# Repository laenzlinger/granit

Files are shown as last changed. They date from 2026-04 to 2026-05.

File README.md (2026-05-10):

# Granit — Offsite Backup Device

Custom carrier board for the Raspberry Pi CM4 Compute Module, designed as a minimal offsite backup appliance.

📖 **[Documentation](https://laenzlinger.github.io/granit/latest/)**




## Overview

PCB 3D Render

A compact, headless device that connects to a remote network and receives encrypted backups
onto an attached hard disk. Designed to be left at a trusted offsite location and managed remotely.

- Raspberry Pi CM4 with PCIe SATA (ASM1061)
- 2.5" or 3.5" HDD/SSD support
- Software-controlled HDD power (GPIO)
- RTC wake for scheduled backups
- USB-C OTG for eMMC flashing
- Hammond 1455 aluminium enclosure

## Roadmap

- **v0.3** — First production run (CM4, 4-layer PCB, JLCPCB)
- **v0.4** — Fix wake/shutdown latch (#31), barrel jack swap (#40), DF40C alignment bosses (#37)
- **v1.0** — Validated design with custom OS image and documentation
- **Future** — Investigating RISC-V SoM support for a fully blob-free variant

## License

[CERN Open Hardware Licence Version 2 - Permissive](https://ohwr.org/cern_ohl_p_v2.txt)

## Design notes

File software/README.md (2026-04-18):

# Granit OS Image & Configuration

## Architecture

- **pi-gen**: builds a minimal Raspberry Pi OS Lite image (packages + boot config)
- **Ansible**: configures all services, security, and monitoring

This split means you can either:
1. Flash the custom image and it's ready to provision
2. Flash stock Raspberry Pi OS and run `make provision`

## Quick Start

```bash
# Option A: Build custom image
make build
# Flash to eMMC via rpiboot + rpi-imager

# Option B: Use stock Raspberry Pi OS Lite
# Flash via rpi-imager, boot, connect Ethernet

# Then provision via Ansible
make provision
```

## Configuration

After provisioning, edit `/etc/granit/sync.conf`:

```bash
SYNC_REMOTE=":sftp,host=100.x.x.x,user=backup,key_file=/home/granit/.ssh/id_ed25519:/backups"
WAKE_HOUR=04
METRICS_URL="http://192.168.1.x:8428/api/v1/import/prometheus"
```

Then enable the backup cycle:

```bash
sudo systemctl enable --now granit-cycle.timer
```

## Ansible Variables

| Variable | Default | Description |
|---|---|---|
| `granit_timezone` | `UTC` | System timezone |
| `granit_wake_hour` | `04` | RTC wake hour (24h) |
| `granit_sync_remote` | `""` | rclone remote path |
| `granit_metrics_url` | `""` | Prometheus remote-write URL |

## Structure

```
software/
├── Makefile              # build image or provision
├── hardware-test.sh      # hardware validation script
├── pi-gen/               # image build (packages + boot config)
│   ├── config
│   └── stage-granit/
│       ├── 00-install-packages/
│       └── 01-config/
└── ansible/              # device configuration
    ├── playbook.yml
    ├── inventory/
    └── roles/granit/
        ├── tasks/main.yml
        ├── templates/
        └── files/
```

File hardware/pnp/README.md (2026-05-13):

# Pick and Place Assembly Plan

OpenPnP job files for Granit v0.3 prototype assembly.

## Usage

```bash
cd hardware
make pnp        # generate board.xml + ensure parts exist
make feeders    # assign parts to feeder slots
make feeder-map # generate interactive HTML feeder map
```

## Feeder Allocation

Defined in [`feeders.csv`](feeders.csv) — the single source of truth for
which part goes in which feeder slot. Apply with `make feeders`.

View the interactive feeder map with `make feeder-map`.

## Hand-Place Components

| Ref | Part | Reason |
| --- | ---- | --- |
| CM1 | Raspberry Pi CM4 | Board-to-board connector |
| J1 | USB-C receptacle | Mid-mount, alignment |
| J3 | UART connector | Vertical |
| J4 | SATA 22-pin | Through-hole pins |

## Assembly Sequence

1. **Stencil** — apply solder paste (tape-hinge, align under microscope)
2. **Machine place** — run OpenPnP job (90 placements)
3. **Inspect** — check QFN-48 (U3) alignment
4. **Reflow** — reflow oven (peak ~210°C leaded / ~245°C lead-free)
5. **Inspect** — check for bridges
6. **Hand-solder** — CM1, J1, J3, J4
7. **Clean** — IPA wash

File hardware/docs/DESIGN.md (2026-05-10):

# Hardware Design Notes

Detailed design decisions and PCB routing guidelines for the Granit carrier board.

## SATA Power Switching

12V and 5V to the SATA connector are switched by P-channel MOSFETs
(Q2, Q3 — FDS4435BZ). GPIO17 (`SATA_PWR_EN`) drives N-channel level shifters
(Q5, Q6 — 2N7002) which pull the P-FET gates low to turn them on.

```
Supply (+12V or +5VP)
  │
  JP5/JP6 pad 1 ─── [bridged default] ─── JP5/JP6 pad 2 (common)
                                              │
  JP5/JP6 pad 3 ─── GND                  R12/R13 (100K)
                                              │
                                         ┌────┴──── Q2/Q3 gate
                                         │
                                    2N7002 drain
                                         │
  SATA_PWR_EN (GPIO17) ── R14 (10K) ── 2N7002 gate
                                         │
                                    2N7002 source
                                         │
                                        GND
```

Two 3-pad solder jumpers (JP5 `SATA_12V_PWR`, JP6 `SATA_5V_PWR`) select the boot default:
- **Pads 1-2 bridged (default):** 100K pull-up to source → FETs OFF → HDD powered on by software
- **Pads 2-3 bridged:** 100K pull-down to GND → FETs ON → HDD powered at boot

GPIO17 high → N-FET on → P-FET gate low → SATA power on.
GPIO17 low or high-Z (boot default) → N-FET off → pull-up holds P-FET off.

R14 (10K) protects GPIO17 against N-FET gate-to-drain failure.

## Power Routing & Netclasses

PCB is fabricated with JLCPCB standard 4-layer stackup (1oz / 35µm copper on all layers).
Track widths are sized per IPC-2221 for outer-layer traces with 20°C temperature rise.

| Netclass | Track Width | Via (pad/drill) | Capacity (1oz, 20°C rise) | Worst-case Load | Nets |
|---|---|---|---|---|---|
| Power 12V | 3.0mm | 1.6mm / 0.8mm | ~3.5A | ~2.5A | `+12V*`, `fused`, `unfused` |
| Power 5V | 2.5mm | 1.6mm / 0.8mm | ~3.2A | ~2.8A | `+5VP`, `VBUS`, `switch` |
| Power 3V3 | 1.0mm | 0.8mm / 0.4mm | ~1.5A | ~0.6A | `+3V3` |

### Routing Guidelines

- Netclass widths are the default for main runs. Neck down to pad width over the last 1–2mm at component pads.
- Use copper pours for 12V and 5V in the PSU area where space allows.
- Use 2–3 parallel vias where power traces change layers.
- Place GND return vias near every power via.
- Keep 12V and 5V routing on top/bottom layers — do not break the inner GND planes.
- Do not route power traces under or parallel to PCIe/SATA/Ethernet differential pairs.

### Layer Strategy

- **Top layer:** PSU components and local routing, signal components
- **Inner 1 (In1.Cu):** GND plane — keep unbroken
- **Inner 2 (In2.Cu):** GND plane — keep unbroken
- **Bottom layer:** Power distribution (5V, 12V, 3.3V to rest of board), signal routing

### Signal Integrity

- **PCIe:** 100Ω differential impedance, matched length, minimize vias and stubs
- **SATA:** 100Ω differential impedance, matched length
- **Ethernet:** 100Ω differential impedance to RJ45 with magnetics
- **USB:** 90Ω differential impedance
- Power traces crossing differential pairs must cross perpendicular (90°)

### AC Coupling Capacitors

6× 100nF 0805 in series on high-speed differential pairs, all placed near the ASM1061:

- **SATA TX** (STXP_A, STXN_A): required by SATA spec (ASM1061 datasheet CTX = 75–200nF)
- **SATA RX** (SRXP_A, SRXN_A): defensive — external interface, can't guarantee drive-side caps
- **PCIe RX** (PCIE_RX_P, PCIE_RX_N): required by CM4 datasheet ("external AC coupling capacitor required")
- **PCIe TX, CLK**: not needed — CM4 has internal AC coupling
- **Ethernet**: not needed — MagJack provides galvanic isolation
- **USB**: not needed — DC-coupled by spec

### ESD Protection

- **USB-C** (J7): USBLC6-2SC6 on D+/D− — user-facing external connector, required
- **SATA** (J9): no ESD protection — internal connector inside metal enclosure, not user-accessible, AC coupling caps provide DC fault isolation
- **Ethernet** (J3): RJ45 MagJack has integrated common-mode chokes and 2kV isolation

## Power Budget

| Rail | Source | Capacity | Worst-case Load |
|---|---|---|---|
| 12V | External PSU | 3A+ recommended | ~2.5A (HDD spin-up + buck converter) |
| 5V | AP64501SP-13 | 3.5A | ~2.8A (CM4 + HDD + USB) |
| 3.3V | NCP1117 LDO | 1A | ~0.6A (ASM1061 + RTC + misc) |

Realistic steady state: ~1.5A (CM4) + 0.5A (HDD) = 2.0A on 5V rail.
HDD spin-up and CM4 peak don't occur simultaneously — SATA power is software-controlled.

### 5V Rail Voltage (5.16V)

The feedback divider (R2=12K, R4=2.2K) sets the buck converter output to 5.16V, intentionally above 5.0V:

- **SATA power FET drop**: FDS4435BZ Rds(on) ~9mΩ → ~18mV loss at 2A
- **Trace/connector resistance**: additional ~30–50mV drop to CM4 pins
- **CM4 undervoltage threshold**: the CM4 triggers low-voltage warnings below ~4.9V

Running at 5.16V ensures the CM4 sees >5.0V after all drops, avoiding undervoltage throttling.

## Ethernet MagJack Pin Mapping

The HR911130A (Hanrun) GbE MagJack follows the standard TIA-568B MDI (Medium Dependent
Interface) pinout. The RJ45 jack pins 1–8 map to Ethernet pairs through internal isolation
transformers, with the transformer outputs on PCB-side pins P1–P10.

### TIA-568B MDI Pair Assignment

In Gigabit Ethernet (1000BASE-T), all 4 pairs are bidirectional. The pair numbering follows
TIA-568B:

| RJ45 Jack Pins | MDI Pair | Function (legacy 10/100) |
|---|---|---|
| 1, 2 | Pair 0 | TX |
| 3, 6 | Pair 1 | RX |
| 4, 5 | Pair 2 | BI (GbE only) |
| 7, 8 | Pair 3 | BI (GbE only) |

Note: Pair 1 (pins 3 and 6) is intentionally split across pins 4 and 5 on the RJ45 jack.
This is a TIA-568 design choice for backwards compatibility with 2-pair telephone wiring.

### HR911130A PCB-Side Pin Mapping

| PCB Pin | Signal | CM4 Net | Notes |
|---|---|---|---|
| P1 | Center tap (primary) | +3.3V via bias resistor | Transformer center tap bias |
| P2 | MDI Pair 0+ | ETH_P0_P | |
| P3 | MDI Pair 0− | ETH_P0_N | |
| P4 | MDI Pair 1+ | ETH_P1_P | Physically far from P7 — normal per TIA-568 |
| P5 | MDI Pair 2+ | ETH_P2_P | |
| P6 | MDI Pair 2− | ETH_P2_N | |
| P7 | MDI Pair 1− | ETH_P1_N | Physically far from P4 — normal per TIA-568 |
| P8 | MDI Pair 3+ | ETH_P3_P | |
| P9 | MDI Pair 3− | ETH_P3_N | |
| P10 | Center tap (secondary) | GND via RC network | Bob Smith termination |
| 11 | LED Green anode | +3.3V via resistor | Link/Activity |
| 12 | LED Green cathode | nLED1 | |
| 13 | LED Yellow cathode | nLED2 | |
| 14 | LED Yellow anode | +3.3V via resistor | Speed |
| S1, S2 | Shield | GND | Chassis ground |

### Routing Notes

- P4 and P7 (Pair 1) are physically separated on the PCB pads because the MagJack's
  internal transformers mirror the RJ45 jack pin arrangement where pins 3 and 6 are split.
  Route them as a matched-length differential pair despite the physical separation at the
  MagJack end.
- All 4 Ethernet pairs require 100Ω differential impedance and length matching.
- The MagJack provides galvanic isolation (2kV) — no external AC coupling or ESD protection
  needed on the Ethernet lines.

## GLOBAL_EN Wake/Shutdown Latch

Controls CM4 power state via the GLOBAL_EN pin (pin 99). Supports cold boot, software
shutdown with latch, RTC alarm wake, and button wake.

### Background

GLOBAL_EN has a CM4-internal pull-up — the module boots when GLOBAL_EN is HIGH or floating,
and powers off completely when GLOBAL_EN is held LOW. After shutdown, CM4 GPIOs go Hi-Z,
so a hardware latch is required to hold GLOBAL_EN LOW and prevent immediate reboot.

### Failed Approach (v0.3)

The v0.3 design used an OR gate (U4, 74AHCT1G32) driving GLOBAL_EN HIGH on wake events,
with Q1 (2N7002) gated by RTC ~INT. R19 (10K pull-up on Q1 gate) held Q1 ON at power-on,
pulling U4 input LOW and preventing boot. The logic was fundamentally inverted.

Workaround: R19 removed. RTC wake non-functional.

### Redesigned Circuit (proposed for v0.4)

Uses a 74LVC1G74 D flip-flop as an SR latch via asynchronous ~PRE (set) and ~CLR (reset).

```
                          ┌───────────────────┐
        RTC ~INT ─────────┤ ~PRE           Q  ├──────── GLOBAL_EN (CM4 pin 99)
                          │                   │
        BUTTON ───────────┤        74LVC1G74  │
                          │                   │
        GPIO6 ────────────┤ ~CLR              │
                          │                   │
                     GND ─┤ CLK            D  ├── GND
                          │                   │
                    +3V3 ─┤ VCC          GND  ├── GND
                          └───────────────────┘

        ~PRE pin external components:
            R1 (100K) ── ~PRE to GND        power-on: forces Q=HIGH via RC delay
            C1 (100nF) ─ ~PRE to GND        holds ~PRE LOW during 3V3 ramp (~10ms)

        ~CLR pin external components:
            R2 (100K) ── ~CLR to +3V3       prevents accidental shutdown at boot

        Existing pull-ups (kept):
            R19 (10K) ── RTC ~INT to +3V3   releases ~PRE HIGH when no alarm
            R6  (10K) ── BUTTON to +3V3     releases ~PRE HIGH when not pressed
```

CLK and D are tied to GND — no clocked operation, only async ~PRE/~CLR control Q.

### Operation

| State | ~PRE | ~CLR | Q (GLOBAL_EN) | Result |
|---|---|---|---|---|
| Cold power-on | LOW (C1 holds during ramp) | HIGH (R2) | HIGH | Boots |
| Running | HIGH (R19+R6 overpower R1) | HIGH | HIGH (latched) | Stays on |
| Shutdown | HIGH | LOW (GPIO6) | LOW | Off |
| Sleeping | HIGH | HIGH (GPIO6 Hi-Z, R2) | LOW (latched) | Stays off |
| RTC wake | LOW (~INT asserts) | HIGH | HIGH | Boots |
| Button wake | LOW (pressed) | HIGH | HIGH | Boots |

### Conflict: ~PRE=LOW and ~CLR=LOW Simultaneously

Per TI SN74LVC1G74 datasheet: both asserted → Q=HIGH (nonstable state). Wake wins over
shutdown. When one releases, output follows whichever remains asserted. This is safe — the
device cannot be held off while a wake event is active.

### Power-On Timing

R1 (100K) + C1 (100nF) gives τ = 10ms. During 3V3 ramp-up, C1 holds ~PRE below VIL,
forcing Q=HIGH. Once 3V3 stabilizes, R19 (10K) and R6 (10K) overpower R1 (100K) and
bring ~PRE HIGH. The latch then holds Q=HIGH until ~CLR is asserted.

### RTC ~INT Lock-Out

DS3231 ~INT is level-triggered — stays LOW until the alarm flag is cleared via I2C. While
~INT is LOW, ~PRE is asserted and the latch cannot be reset (shutdown is blocked). This is
acceptable because GLOBAL_EN must be HIGH during boot anyway. The boot script must clear
the alarm early:

```bash
i2cset -y 1 0x68 0x0F 0x00  # Clear DS3231 status register (alarm flags)
```

### GPIO6 Float Protection

GPIO6 defaults to Hi-Z (input) at boot. R2 (100K to +3V3) keeps ~CLR HIGH, preventing
accidental shutdown. GPIO6 has no boot-time alternate function that would drive it LOW.

### Debouncing

Not required. ~PRE is level-sensitive — button bounce repeatedly forces Q=HIGH, which is
idempotent. CM4 PMIC power-up (~100ms) is far slower than bounce (~1–10ms).

### Parts Change from v0.3

| Remove | Add |
|---|-----|
| U4 (74AHCT1G32) | 74LVC1G74DP,125 (Nexperia, TSSOP-8, IPN: U-012) |
| Q1 (2N7002) | R1: 100K to GND on ~PRE |
| R16 (GLOBAL_EN pull-up) | R2: 100K to +3V3 on ~CLR |
| R18 (Q1 drain pull-up) | C1: 100nF on ~PRE to GND |

R19 (RTC_INT pull-up) and R6 (BUTTON pull-up) are kept.

### Software Configuration

```ini
# CM4 EEPROM (rpi-eeprom-config)
POWER_OFF_ON_HALT=1       # PMIC fully powers off on shutdown
WAKE_ON_GPIO=0            # Only wake via GLOBAL_EN toggle

# config.txt
dtoverlay=gpio-poweroff,gpiopin=6,active_low=1
```

### Open Validation

- [ ] Verify GPIO6 does not glitch LOW during boot (scope on prototype)
- [ ] Measure actual power-on RC timing with chosen component values

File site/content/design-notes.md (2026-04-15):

---
title: Design Notes
weight: 50
---

For detailed circuit design notes, PCB routing guidelines, and netclass definitions,
see [hardware/DESIGN.md](https://github.com/laenzlinger/granit/blob/main/hardware/DESIGN.md).

## Key Design Decisions

- **ASM1061 over USB-to-SATA bridges**: Native PCIe SATA controller using the
  standard Linux `ahci` driver. No proprietary firmware blob required — the SPI
  flash footprint can be left unpopulated. SMART works natively without SAT
  translation hacks. Full SATA III throughput on both CM4 and CM5.

- **12V DC input**: Required for 3.5" HDD support (spindle motor needs 12V).
  AP64501SP-13 accepts 3.8–28V. Both barrel jack and screw terminal footprints
  provided — populate one at assembly time.

- **Reuse from pedalboard-hw**: CM connector, power supply (AP64501SP-13 buck +
  NCP1117 LDO), USB power switch (AP2553W6), KiCad symbol/footprint library.

- **USB-C OTG**: Single USB-C connector for eMMC flashing (`rpiboot`) and USB
  mass storage gadget mode (initial backup seeding). USB 2.0 device mode only,
  with USBLC6-2SC6 ESD protection.

- **SATA power control**: 12V and 5V to the SATA connector are software-controlled
  via GPIO5. HDD is off by default at boot — powered on explicitly by software.
  Solder jumpers (JP5, JP6) allow changing the default without a PCB respin.

- **Power budget**: 12V @ 2A (3.5" HDD spin-up) + 5V @ 2.3A peak (CM4 + electronics)
  — use a 12V/3A+ PSU.

- **Boot and storage strategy**: Full OS on CM4 eMMC (no SD card slot), SATA HDD
  dedicated to LUKS-encrypted backup storage only. No SD card — eMMC is more
  reliable for a deploy-and-forget device.

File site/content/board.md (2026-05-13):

---
title: Board
type: board
weight: 20
---

For detailed circuit design notes, PCB routing guidelines, and netclass definitions,
see [hardware/docs/DESIGN.md](https://github.com/laenzlinger/granit/blob/main/hardware/docs/DESIGN.md).

{{% callout type="warning" %}}
**Power budget:** 12V @ 2A (3.5" HDD spin-up) + 5V @ 2.3A peak (CM4 + electronics) — use a 12V/3A+ PSU.
{{% /callout %}}

## Key Design Decisions

{{% details title="ASM1061 over USB-to-SATA bridges" %}}
Native PCIe SATA controller using the standard Linux `ahci` driver. No proprietary firmware blob required — the SPI flash footprint can be left unpopulated. SMART works natively without SAT translation hacks. Full SATA III throughput on both CM4 and CM5.
{{% /details %}}

{{% details title="12V DC input" %}}
Required for 3.5" HDD support (spindle motor needs 12V). AP64501SP-13 accepts 3.8–28V. Both barrel jack and screw terminal footprints provided — populate one at assembly time.
{{% /details %}}

{{% details title="USB-C OTG" %}}
Single USB-C connector for eMMC flashing (`rpiboot`) and USB mass storage gadget mode (initial backup seeding). USB 2.0 device mode only, with USBLC6-2SC6 ESD protection.
{{% /details %}}

{{% details title="SATA power control" %}}
12V and 5V to the SATA connector are software-controlled via GPIO5. HDD is off by default at boot — powered on explicitly by software. Solder jumpers (JP5, JP6) allow changing the default without a PCB respin.
{{% /details %}}

{{% details title="Boot and storage strategy" %}}
Full OS on CM4 eMMC (no SD card slot), SATA HDD dedicated to backup storage only. No SD card — eMMC is more reliable for a deploy-and-forget device. Backup data is encrypted client-side (e.g. by Restic or rclone crypt). Full-disk encryption via LUKS is optional.
{{% /details %}}

{{% details title="Reuse from pedalboard-hw" %}}
CM connector, power supply (AP64501SP-13 buck + NCP1117 LDO), USB power switch (AP2553W6), KiCad symbol/footprint library.
{{% /details %}}

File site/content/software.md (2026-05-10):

---
title: Software
weight: 55
---

Custom Raspberry Pi OS Lite image with Ansible-based provisioning.
Source: [`software/`](https://github.com/laenzlinger/granit/tree/main/software)

## Architecture

- **pi-gen**: builds a minimal image (packages + boot config)
- **Ansible**: configures all services, security, and monitoring

You can also skip the custom image and provision stock Raspberry Pi OS directly.

## Hardware Support

### PCIe SATA (ASM1061)

```
dtparam=pciex1
dtparam=pciex1_gen=2
```

The SATA drive appears as `/dev/sda` once connected and powered.

### DS3231 RTC

```
dtparam=i2c_arm=on
dtoverlay=i2c-rtc,ds3231
```

System clock is set from the RTC on boot. The RTC alarm triggers scheduled wake.

### HDD Power Control

GPIO5 (`SATA_PWR_EN`) controls the P-FET power switches for SATA 12V and 5V.
Managed by `granit-hdd-power` and `granit-hdd-shutdown` services.

### Hardware Watchdog

```
dtparam=watchdog=on
```

{{% callout type="info" %}}
systemd pings the watchdog every 15 seconds. If the system hangs, the watchdog triggers a hardware reset. Critical for an unattended remote device.
{{% /callout %}}

### UART Debug Console

Serial console on GPIO14/15 at 115200 baud via JST-SH 3-pin header (J3).

## Backup Cycle

{{% steps %}}

### Boot

RTC alarm wakes the CM4.

### Wait

2 minutes for network connectivity.

### Sync

rclone pulls from configured remote.

### Schedule

Sets RTC wake alarm for next day.

### Poweroff

Safe HDD shutdown, then power off.

{{% /steps %}}

{{% callout %}}
**Maintenance mode:** `touch /var/lib/granit-maintenance` to skip poweroff.
{{% /callout %}}

## Monitoring

{{< tabs items="Push (default),Pull (optional)" >}}
{{< tab >}}
After each sync, metrics are pushed to a configurable Prometheus remote-write endpoint (`METRICS_URL`). Works with VictoriaMetrics, Prometheus Pushgateway, or any compatible receiver.

Metrics: `granit_sync_duration_seconds`, `granit_sync_success`, `granit_disk_used_bytes`, `granit_disk_total_bytes`.
{{< /tab >}}
{{< tab >}}
`prometheus-node-exporter` on port 9100 with RPi throttle/undervoltage metrics. Disabled by default — enable if you have a scraper that can reach the device.
{{< /tab >}}
{{< /tabs >}}

## Security

{{% details title="Security hardening details" %}}
- SSH key-only, root login disabled
- UFW firewall (SSH only)
- fail2ban (5 attempts → 1h ban)
- Automatic security updates
- Kernel hardening (sysctl)
{{% /details %}}

## Configuration

`/etc/granit/sync.conf`:

```bash
SYNC_REMOTE=":sftp,host=100.x.x.x,user=backup,key_file=..."
WAKE_HOUR=04
METRICS_URL="http://192.168.1.x:8428/api/v1/import/prometheus"
```

## Provisioning

{{% steps %}}

### Build the image

```bash
cd software
make build   # pi-gen via Docker
```

### Flash and boot

Flash the image to CM4 eMMC via `rpiboot`, then power on.

### Provision

```bash
cd software
make provision  # runs Ansible playbook
```

{{% /steps %}}

{{% details title="Ansible variables" %}}
| Variable | Default | Description |
|---|---|---|
| `granit_timezone` | `UTC` | System timezone |
| `granit_wake_hour` | `04` | RTC wake hour |
| `granit_sync_remote` | `""` | rclone remote path |
| `granit_metrics_url` | `""` | Prometheus push URL |
{{% /details %}}

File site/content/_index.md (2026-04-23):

---
title: Overview
weight: 10
---

<div class="hero-layout">
PCB 3D Render
<div>

Custom carrier board for the Raspberry Pi CM4 Compute Module, designed as a
minimal offsite backup appliance.

</div>
</div>

**The 3-2-1 backup rule** says: keep **3** copies of your data, on **2**
different media, with **1** copy offsite. The first two are easy — a NAS with
mirrored disks covers them. The offsite copy is the hard part.

Granit takes a different approach: a small, silent box you leave at a friend's
or family member's house. It connects to their network, receives encrypted
backups over a VPN, and stores them on a local hard disk. You keep full control
of your data.

## Key Components

| Component | Description |
|---|---|
| Raspberry Pi CM4 | Compute module (PCIe Gen 2 x1) |
| ASM1061 | PCIe to 2-port SATA III controller |
| 2.5" or 3.5" SATA HDD/SSD | Backup storage |
| DS3231 RTC | Battery-backed real-time clock with alarm wake |
| AP64501SP-13 | 3.5A DC-DC buck converter |
| USB-C | USB 2.0 OTG with ESD protection |

## Architecture

Architecture Diagram

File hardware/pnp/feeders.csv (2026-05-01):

feeder | part
LV08-01 | C_0805-18p
LV08-02 | C_0805-1n
LV08-03 | C_0805-1.2n
LV08-04 | C_0805-100n
LV08-05 | C_0805-10u
LV08-06 | R_0805-10R
LV08-07 | R_0805-330R
LV08-08 | R_0805-750R
LV08-09 | R_0805-2K2
LV08-10 | R_0805-4K7
LV08-11 | R_0805-5K1
LV08-12 | R_0805-10K
LV08-13 | R_0805-12K
LV08-14 | R_0805-20K
LV08-15 | R_0805-100K
RV08-01 | LED_0805-LED G
RV08-02 | LED_0805-LED R
RV08-03 | SOT-23-2N7002
RV08-04 | SOT-23-5-74AHCT1G32
RV08-05 | SOT-23-5-74AHCT1G125
RV08-06 | SOT-23-6-USBLC6-2SC6
RV08-07 | XTAL-2016-25MHz
RH12-01 | SOT-223-NCP1117-3.3_SOT223
RH12-02 | SOIC-8-FDS4435BZ
RH12-03 | SOIC-8-EP-AP64501SP-13
RH12-04 | SOIC-8-DS3231MZ
RH12-05 | FUSE-2512-3A
RH12-06 | WS2812B-5050-WS2812B-5mm
RH12-07 | SW-SKRTLAE010-SW_Push
RH12-08 | TANT-D-100u
RV16-01 | QFN-48-7x7-ASM1061
RV16-02 | IND-6045-SRN6045TA-3R3Y
RV16-03 | SW-PCM12-PCM12SMTR
RV16-04 | ECAP-6.3x7.7-100uF/25V

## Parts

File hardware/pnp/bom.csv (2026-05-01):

Value | Footprint | IPN
CR2032 | Battery:BatteryHolder_Keystone_103_1x20mm | BT-001
100n | Capacitor_SMD:C_0805_2012Metric | C-001
18p | Capacitor_SMD:C_0805_2012Metric | C-015
10u | Capacitor_SMD:C_0805_2012Metric | C-003
100uF/25V | Capacitor_SMD:CP_Elec_6.3x7.7 | C-020
1.2n | Capacitor_SMD:C_0805_2012Metric | C-005
1n | Capacitor_SMD:C_0805_2012Metric | C-004
100u | Capacitor_Tantalum_SMD:CP_EIA-7343-31_Kemet-D | C-006
CM4 | granit:Raspberry-Pi-4-Compute-Module | J-002
WS2812B-5mm | LED_SMD:LED_WS2812B_PLCC4_5.0x5.0mm_P3.2mm | D-007
LED R | LED_SMD:LED_0805_2012Metric | D-002
LED G | LED_SMD:LED_0805_2012Metric | D-001
3A | Fuse:Fuse_2512_6332Metric | F-002
USB_C_Receptacle_USB2.0_14P | Connector_USB:USB_C_Receptacle_GCT_USB4105-xx-A_16P_TopMnt_Horizontal | J-004
PCM12SMTR | Button_Switch_SMD:SW_SPDT_PCM12 | J-005
BM03B-SRSS-TB | Connector_JST:JST_SH_BM03B-SRSS-TB_1x03-1MP_P1.00mm_Vertical | J-006
SATA_22pin | Connector_SATA_SAS:SATA_Amphenol_10029364-001LF_Horizontal | J-007
12V Barrel | granit:BarrelJack_Wuerth_6941xx301002 | J-001
HR911130A | granit:HANRUN_HR911130A | J-008
SRN6045TA-3R3Y | Inductor_SMD:L_Bourns_SRN6045TA | L-001
2N7002 | Package_TO_SOT_SMD:SOT-23 | Q-003
FDS4435BZ | granit:SO08-E3 | Q-001
5K1 | Resistor_SMD:R_0805_2012Metric | R-019
330R | Resistor_SMD:R_0805_2012Metric | R-018
12K | Resistor_SMD:R_0805_2012Metric | R-007
750R | Resistor_SMD:R_0805_2012Metric | R-020
10K | Resistor_SMD:R_0805_2012Metric | R-002
10R | Resistor_SMD:R_0805_2012Metric | R-001
4K7 | Resistor_SMD:R_0805_2012Metric | R-003
100K | Resistor_SMD:R_0805_2012Metric | R-004
2K2 | Resistor_SMD:R_0805_2012Metric | R-005
20K | Resistor_SMD:R_0805_2012Metric | R-006
SW_Push | Button_Switch_SMD:SW_Push_1P1T-MP_NO_Horizontal_Alps_SKRTLAE010 | SW-003
TestPoint | TestPoint:TestPoint_Pad_2.0x2.0mm
USBLC6-2SC6 | Package_TO_SOT_SMD:SOT-23-6 | U-011
74AHCT1G125 | Package_TO_SOT_SMD:SOT-23-5 | U-008
ASM1061 | granit:QFN50P700X700X90-49N-D | U-009
74AHCT1G32 | Package_TO_SOT_SMD:SOT-23-5 | U-003
DS3231MZ | Package_SO:SOIC-8_3.9x4.9mm_P1.27mm | U-010
NCP1117-3.3_SOT223 | Package_TO_SOT_SMD:SOT-223-3_TabPin2 | U-002
AP64501SP-13 | granit:SOIC-8-1EP_3.9x4.9mm_P1.27mm_EP2.95x4.9mm_Mask2.71x3.4mm_ThermalVias | U-001
25MHz | Crystal:Crystal_SMD_2016-4Pin_2.0x1.6mm | Y-003

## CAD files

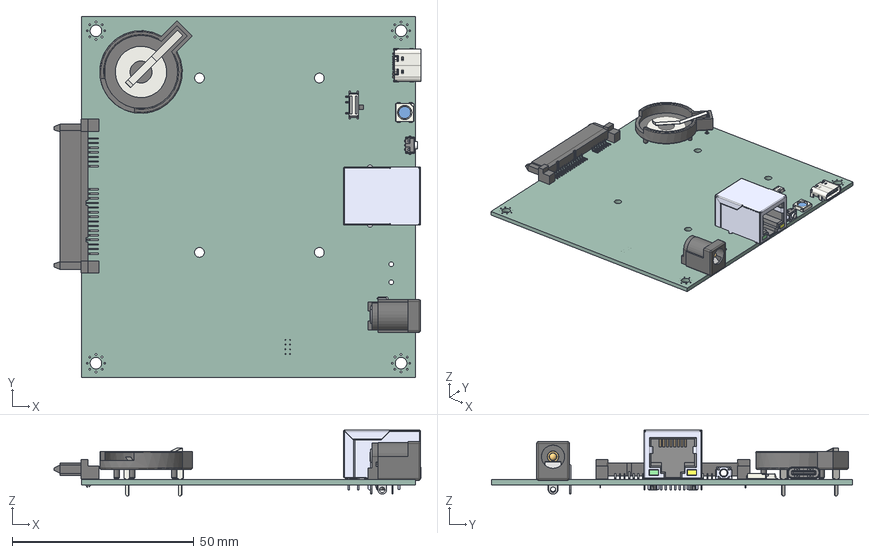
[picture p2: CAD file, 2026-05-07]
mechanical/granit-pcb.step
101.0 x 99.5 x 18.2 mm
SATA_Amphenol_10029364-001LF_Horizontal
LED_WS2812B_PLCC4_5.0x5.0mm_P3.2mm
SW_SPDT_PCM12
BatteryHolder_Keystone_103_1x20mm
SW_Alps_SKRTLAE010
USB_C_Receptacle_GCT_USB4105-xx-A_16P_TopMnt_Horizontal
6941xx301002
694106301002_PinContact
6941xx301002_Back
6941xx301002_PinContact2
6941xx301002_PinLame
6941xx301002_PinBis
HR911130A
granit_PCB

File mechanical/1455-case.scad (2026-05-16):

// Hammond 1455 series parametric case model
// Accurate cross-section from STEP analysis of real 1455L/N/T parts.
//
// The 1455 is an extruded aluminium U-channel body with:
//   - Removable belly plate (bottom lid, slides in from end)
//   - Lip at top for snap/screw lid retention
//   - PCB card guide slots on both side walls
//   - End frames with screw bosses for end plates
//
// Usage:
//   Full case:    openscad -o case.stl 1455-case.scad
//   Body only:    openscad -o body.stl -D 'render_part="body"' 1455-case.scad
//   Lid only:     openscad -o lid.stl -D 'render_part="lid"' 1455-case.scad
//   End plate:    openscad -o plate.stl -D 'render_part="end_plate"' 1455-case.scad
//
//   Profile:      -D 'profile="N"'
//   Length:       -D 'length=160'

// ── Parameters ──────────────────────────────────────────────────────────────

profile = "N";          // J=78x27, K=78x43, L=103x30.5, N=103x53, T=165x51.5
length  = 160;          // body length (mm)
render_part = "all";    // all, body, lid, end_plate, exploded

// ── Profile Lookup ──────────────────────────────────────────────────────────

function profile_dims(p) =
    p == "J" ? [78, 27] :
    p == "K" ? [78, 43] :
    p == "L" ? [103, 30.5] :
    p == "N" ? [103, 53] :
    p == "T" ? [165, 51.5] :
    [103, 53];

dims  = profile_dims(profile);
W     = dims[0];        // outer width
H     = dims[1];        // outer height (depth)

// ── Dimensions (from STEP analysis of Hammond 1455L) ────────────────────────

wall        = 1.5;      // wall thickness (sides and top)
corner_r    = 4.0;      // outer corner radius
inner_r     = corner_r - wall;  // inner corner radius (2.5mm)

// Belly plate (removable bottom lid)
belly_w     = W - 2*5.55;      // 91.9mm for 103mm wide
belly_t     = 1.5;             // plate thickness
belly_groove_d = 4.22;         // groove depth in body (plate + clearance)
belly_lip   = 0.38;            // retention lip height

// Top lip (body overhangs inward at top opening)
lip_h       = 1.5;     // lip height
lip_w       = (W - 89.14) / 2; // ~6.93mm overhang each side

// PCB card guide slots (on both side walls)
slot_w      = 1.5;      // slot width (accepts 1.6mm PCB with clearance)
slot_d      = 2.0;      // slot depth into wall (from inner face)
slot_spacing = 3.5;     // spacing between slot centers

// End plate guide channels (wider grooves between PCB slots)
// The end plate slides into these channels from the end of the extrusion.
// They run between each pair of PCB slots and extend to the inner wall face.
channel_d   = 2.5;      // channel depth (slightly deeper than PCB slots)
channel_w   = 2.0;      // channel width (gap between adjacent slots)

// Slot count and first position per profile (from STEP measurements):
//   First slot: 8.18mm from top (lip), last slot: 8.32mm from bottom (open side)
//   Spacing: 3.50mm, consistent across all profiles.
function slot_config(p) =
    p == "J" ? [1, 13.5] :
    p == "K" ? [8, 8.18] :
    p == "L" ? [5, 8.19] :
    p == "N" ? [12, 8.18] :
    p == "T" ? [11, 8.18] :
    [12, 8.18];

_sc = slot_config(profile);
slot_count = _sc[0];
slot_first = _sc[1];
slot_from_top = [for (i = [0:slot_count-1]) slot_first + i * slot_spacing];

// Decorative grooves on outer side walls (semicircular notches)
groove_r    = 0.38;     // groove radius (from STEP: R=0.380 arcs)
// Grooves are evenly spaced in the flat wall zone between corners.
// From STEP: first groove ~(corner_r + 1.84)mm from top
groove_zone_top = corner_r + 1.84;
groove_zone_bot = H - corner_r - 1.84;
// Groove count: ~1 per 4.9mm of flat zone (from 1455T measurement)
groove_count = max(2, floor((groove_zone_bot - groove_zone_top) / 4.9) + 1);
groove_spacing_actual = (groove_zone_bot - groove_zone_top) / (groove_count - 1);
groove_from_top = [for (i = [0:groove_count-1]) groove_zone_top + i * groove_spacing_actual];

// Screw boss geometry
// Each corner has a solid block (rounded on outside) with a screw hole.
// The cavity cut removes the inner portion, leaving material around the hole.
boss_hole_d = 3.5;      // screw hole diameter (#4-40 / M3 clearance)
boss_size   = 6.8;      // boss block size (measured from real case)

// End plate
plate_t     = 1.5;
plate_w     = W - 0.13; // 102.87mm (slight clearance)
plate_h     = H - 0.03; // 30.48mm for 1455L
plate_corner_r = 3.94;  // from Hammond STEP
plate_screw_d  = 3.5;   // clearance for #4-40 / M3
plate_screw_inset_x = 4.0;
plate_screw_inset_y = 4.0;

$fn = 48;

// ── Modules ─────────────────────────────────────────────────────────────────

// Rounded rectangle (2D)
module rrect(w, h, r) {
    offset(r=r) offset(delta=-r)
        square([w, h], center=true);
}

// Screw boss rails are just regular horizontal ridges at the corner positions.
// No special module needed — they're part of the rail zone material.

// Complete body cross-section (2D) — everything that comes out of the extrusion die
// Approach: thick side walls (wall + rail zone), then cut slots where PCB goes.
// The boss areas are simply uncut sections of the rail zone.
module body_profile_2d() {
    rail_zone = channel_d;

    difference() {
        union() {
            // Solid outer shell (thick walls include rail material)
            rrect(W, H, corner_r);

            // Corner boss blocks (all 4 corners, rounded to match case profile)
            for (sx = [-1, 1])
                for (sy = [-1, 1])
                    translate([sx * (W/2 - corner_r), sy * (H/2 - corner_r)])
                        offset(r=2) offset(delta=-2)
                            square([boss_size, boss_size], center=true);
        }

        // Main inner cavity (stops at boss blocks on both ends)
        boss_inner_x = (W/2 - corner_r) - boss_size/2;
        boss_top_y = -(H/2 - corner_r) + boss_size/2;   // top edge of bottom boss
        boss_bot_y_top = (H/2 - corner_r) - boss_size/2; // bottom edge of top boss
        cavity_w = W - 2*(wall + rail_zone);
        cavity_bot = boss_top_y;
        cavity_top = boss_bot_y_top;
        cavity_h = cavity_top - cavity_bot;
        cavity_cy = (cavity_top + cavity_bot) / 2;
        translate([0, cavity_cy])
            square([cavity_w, cavity_h], center=true);

        // Open the bottom of the U between the boss blocks
        opening_w = boss_inner_x * 2;
        opening_top = H/2 - lip_h;
        translate([0, (-H/2 + opening_top) / 2])
            square([opening_w, opening_top + H/2 + 0.01], center=true);

        // Belly plate channel (stops at boss blocks)
        belly_channel_w = W - 2*(corner_r + boss_size/2);
        translate([0, -H/2 + belly_groove_d/2])
            square([belly_channel_w, belly_groove_d + 0.01], center=true);

        // Screw holes through corner bosses (all 4 corners)
        for (sx = [-1, 1])
            for (sy = [-1, 1])
                translate([sx * (W/2 - corner_r), sy * (H/2 - corner_r)])
                    circle(d=boss_hole_d, $fn=24);

        // Belly plate slot through bottom boss blocks (from inner edge to center)
        for (sx = [-1, 1])
            translate([sx * (W/2 - corner_r - boss_size/4), -(H/2 - corner_r)])
                square([boss_size/2 + 0.01, belly_t + 0.2], center=true);

        // Diagonal slot through top boss blocks (45° toward interior)
        for (sx = [-1, 1]) {
            bx = sx * (W/2 - corner_r);
            by = (H/2 - corner_r);
            translate([bx, by])
                rotate(sx > 0 ? 180+45 : -45)
                    translate([boss_size/2.5, 0])
                        square([boss_size*0.8, belly_t + 0.2], center=true);
        }

        // PCB slot cuts — narrow gaps through the rail zone
        // Only cut where there's no boss block
        for (pos = slot_from_top) {
            slot_cy = H/2 - pos;
            if (slot_cy > -H/2 + corner_r + boss_size/2)  // above bottom boss
            for (side = [-1, 1])
                translate([side * (W/2 - wall - rail_zone/2), slot_cy])
                    square([rail_zone + 0.01, slot_w], center=true);
        }

        // Decorative grooves on outer side walls
        for (g = groove_from_top) {
            gy = H/2 - g;
            for (side = [-1, 1])
                translate([side * W/2, gy])
                    circle(r=groove_r, $fn=16);
        }
    }
}

// Body: pure extrusion — no post-machining operations
module body() {
    linear_extrude(length, center=true)
        body_profile_2d();
}
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

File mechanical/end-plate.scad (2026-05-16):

// Granit — Hammond 1455 end plate with connector cutouts
// Parametric: works for both slim (1455L) and wide (1455T) variants
//
// Usage:
//   3D (STL for printing):  openscad -o plate.stl -D 'variant="slim"' end-plate.scad
//   2D (DXF for CNC):       openscad -o plate.dxf -D 'variant="slim"' -D 'mode="2d"' end-plate.scad

/* [Output Mode] */
mode = "3d"; // [3d, 2d]

/* [Case Variant] */
variant = "slim"; // [slim, wide, compact]

/* [Plate Dimensions (from Hammond STEP)] */
plate_w = (variant == "slim") ? 103 : 165;
plate_h = (variant == "slim") ? 30.5 : 51.5;
plate_t = 1.5;

// Screw holes (Hammond 1455: #4-40 UNC ≈ M3, 4mm inset)
screw_d = 3.5;
screw_cs_d = 6.5;
screw_inset_x = 4.0;
screw_inset_y = 4.0;

// Corner radius (from Hammond STEP: 3.94mm)
corner_r = 3.94;

/* [PCB Position Inside Case] */
board_len = 99.5;
pcb_offset_x = 0;
// PCB bottom height from plate bottom:
//   slim/wide: 5.0mm (standoffs from belly plate)
//   compact: 31.6mm from plate bottom (wall + rail + HDD + gap)
//            plate is rotated 180° so cutouts flip to match upside-down PCB
pcb_bottom_y = (variant == "compact") ? 7.5 : 5.0;
pcb_t = 1.6;
pcb_surface_y = pcb_bottom_y + pcb_t;

/* [Connector Cutouts — from KiCad PCB dimensions] */
// Barrel Jack (J7) — 17mm from connector edge
bj_pcb_y = 103;
bj_w     = 9.0;  // datasheet: body width
bj_h     = 9.0;  // datasheet: body height above PCB

// RJ45 Ethernet (J8) — 50mm from connector edge
rj45_pcb_y = 70;
rj45_w     = 16.2;
rj45_h     = 13.1;

// USB-C (J1) — 86mm from connector edge
usbc_pcb_y = 34;
usbc_w     = 9.0;
usbc_h     = 3.2;

// Button (SW1) — 64mm from connector edge
btn_pcb_y = 56;
btn_d     = 3.0;

// NeoPixel LED (D1) — 73mm from connector edge
led_pcb_y = 47;
led_d     = 3.0;

// Button and LED center height above PCB surface
btn_led_center_h = 1.5;

/* [Tolerances] */
clearance = 0.5;

// ============================================================

function pcb_y_to_plate_x(kicad_y) =
    (plate_w - board_len) / 2 + pcb_offset_x + (board_len - (kicad_y - 20.5));

// 2D profile (used for both DXF export and 3D extrusion)
module plate_2d() {
    difference() {
        // Rounded rectangle outline
        offset(r=corner_r) offset(delta=-corner_r)
            square([plate_w, plate_h]);

        // Screw holes
        for (px = [screw_inset_x, plate_w - screw_inset_x])
            for (py = [screw_inset_y, plate_h - screw_inset_y])
                translate([px, py])
                    circle(d=screw_d, $fn=24);

        // Rectangular cutouts (bottom-aligned to PCB surface)
        for (p = [[bj_pcb_y, bj_w, bj_h],
                   [rj45_pcb_y, rj45_w, rj45_h],
                   [usbc_pcb_y, usbc_w, usbc_h]]) {
            c = clearance;
            px = pcb_y_to_plate_x(p[0]);
            translate([px - (p[1]+c)/2, pcb_surface_y])
                square([p[1]+c, p[2]+c]);
        }

        // Round cutouts (button + LED at same height)
        for (ky = [btn_pcb_y, led_pcb_y]) {
            c = clearance;
            px = pcb_y_to_plate_x(ky);
            py = pcb_surface_y + btn_led_center_h;
            translate([px, py])
                circle(d=btn_d+c, $fn=32);
        }
    }
}

if (mode == "2d") {
    plate_2d();
} else {
    if (variant == "compact") {
        // Mirror both X and Y for upside-down PCB orientation
        linear_extrude(plate_t)
            translate([plate_w, plate_h])
                rotate(180)
                    plate_2d();
    } else {
        linear_extrude(plate_t) plate_2d();
    }
}

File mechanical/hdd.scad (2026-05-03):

// Granit — simplified HDD models with SATA connector slot
//
// SATA connector position per SFF-8201 (2.5") and SFF-8301 (3.5").
// Pin positions from SFF-8223 (SATA connector specification).
//
// Usage:
//   openscad -o 2.5inch_HDD.stl -D 'drive="2.5"' hdd.scad
//   openscad -o 3.5inch_HDD_NAS.stl -D 'drive="3.5"' hdd.scad

/* [Drive Selection] */
drive = "2.5"; // [2.5, 3.5]

/* [2.5" Drive — SFF-8201] */
len_25    = 100.2;
width_25  = 69.85;
height_25 = 9.5;
// SATA connector offset per SFF-8201: pin S1 at 7.11mm from reference edge
slot_y_min_25 = 7.11;
slot_y_max_25 = 7.11 + 34.6;

/* [3.5" Drive — SFF-8301] */
len_35    = 147.0;
width_35  = 101.6;
height_35 = 26.1;
// SATA connector offset per SFF-8301: pin S1 at 11.1mm from reference edge
slot_y_min_35 = 11.1;
slot_y_max_35 = 11.1 + 34.6;

/* [SATA Receptacle — SFF-8223] */
slot_depth  = 5.0;  // depth into drive face
slot_height = 8.6;  // receptacle opening height

// ============================================================

l  = (drive == "2.5") ? len_25    : len_35;
w  = (drive == "2.5") ? width_25  : width_35;
h  = (drive == "2.5") ? height_25 : height_35;
sy = (drive == "2.5") ? slot_y_min_25 : slot_y_min_35;
sw = (drive == "2.5") ? slot_y_max_25 - slot_y_min_25
                      : slot_y_max_35 - slot_y_min_35;

difference() {
    cube([l, w, h]);
    translate([l - slot_depth, sy, 0])
        cube([slot_depth + 1, sw, slot_height]);
}

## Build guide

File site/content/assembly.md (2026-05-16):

---
title: Assembly
type: assembly
weight: 45
---

The PCB (92 × 99.5mm) supports three enclosure layouts using standard Hammond 1455 cases.

## Enclosure Variants

| Variant | Layout | Case | HDD | Dimensions (W×H×L) |
|---|---|---|-----|---|
| Slim | side-by-side | Hammond 1455L2201 | 2.5" | 103 × 30.5 × 220mm |
| Compact | sandwich | Hammond 1455T1601 | 3.5" | 165 × 51.5 × 160mm |
| Wide | side-by-side | Hammond 1455T2601 | 3.5" | 165 × 51.5 × 260mm |

**Slim variant (2.5" SSD):** PCB and drive sit side-by-side with the SATA connector
direct-mating between them.

**Compact variant (3.5" HDD):** PCB stacks on top of the HDD (sandwich layout),
connected with a short 22-pin SATA extension cable (right-angle end on HDD side).

**Wide variant (3.5" HDD):** PCB and drive sit side-by-side in a wider case.
The 1455T profile (165mm wide) may have longer lead times than the common 103mm-wide cases.

## Compact Variant — SATA Cabling

The sandwich layout requires a short SATA cable between the PCB (on top) and the HDD (below).

**Parts needed:**
1. SATA 22-pin right-angle adapter (male-to-female, 90° bend) — mounts on the HDD
2. SATA 22-pin extension cable (~10cm, straight connectors)

**Assembly:**
- Push the HDD to the front of the case (SATA connector facing the end plate)
- Attach the right-angle adapter to the HDD's SATA port (bends the connector flat against the drive top, ~12mm height)
- Route the extension cable from the adapter up to the PCB's J4 connector
- The 13mm space behind the HDD (case is 160mm, drive is 147mm) provides room for the cable to fold

**Clearance budget:**
- HDD top to PCB bottom: ~21mm available
- Right-angle adapter height: ~12mm
- Cable bend: ~5mm
- Margin: ~4mm

## End Plate

The connector-side end plate has cutouts for:
barrel jack (12V DC), RJ45 (Ethernet), USB-C (OTG), tactile button, and RGB LED (light pipe).

Parametric design in OpenSCAD — generate for CNC machining or 3D printing:

```bash
# DXF for CNC laser/mill (variants: slim, compact, wide)
openscad -o end-plate-compact.dxf -D 'variant="compact"' -D 'mode="2d"' end-plate.scad

# STL for 3D printing
openscad -o end-plate-compact.stl -D 'variant="compact"' -D '$fn=64' end-plate.scad
```

## Pick and Place

Interactive [feeder map](/granit/latest/feeder-map.html) showing the OpenPnP feeder allocation for machine placement.

## Downloads

| File | Format | Description |
|---|---|---|
| [end-plate.scad](https://github.com/laenzlinger/granit/raw/main/mechanical/end-plate.scad) | OpenSCAD | Parametric end plate source |
| [1455-case.scad](https://github.com/laenzlinger/granit/raw/main/mechanical/1455-case.scad) | OpenSCAD | Parametric Hammond 1455 case |

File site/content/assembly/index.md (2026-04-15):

---
title: Assembly
weight: 45
---

## Enclosure Options

The PCB (92 × 99.5mm) fits both Hammond 1455 enclosure variants, held by a
3D-printed internal frame. PCB and HDD sit side-by-side, SATA connector
direct-mates between them.

### Slim — Hammond 1455L2201

220 × 103 × 30.5 mm, 2.5" HDD only.

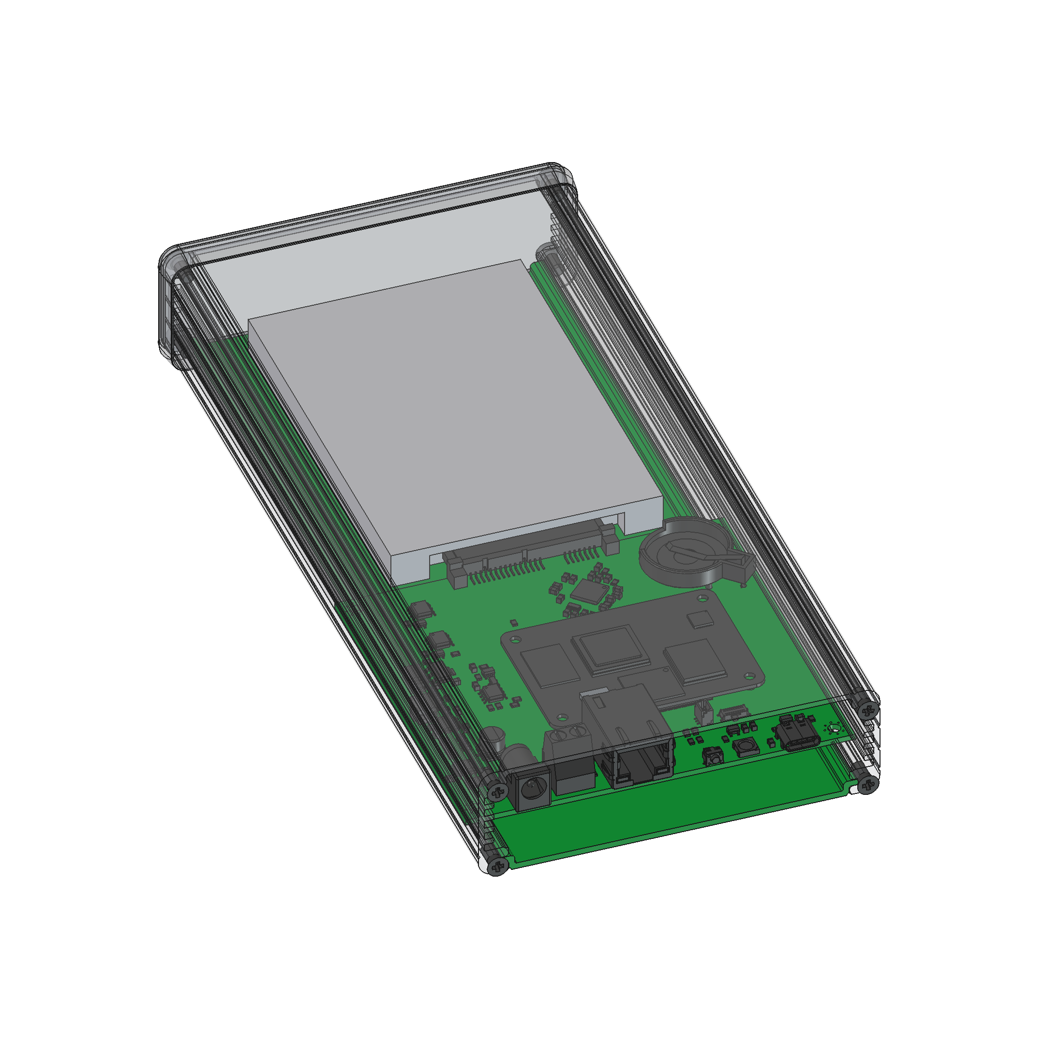
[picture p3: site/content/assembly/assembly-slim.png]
Slim assembly


### Wide — Hammond 1455T2601

260 × 160 × 51.5 mm, 2.5" or 3.5" HDD.

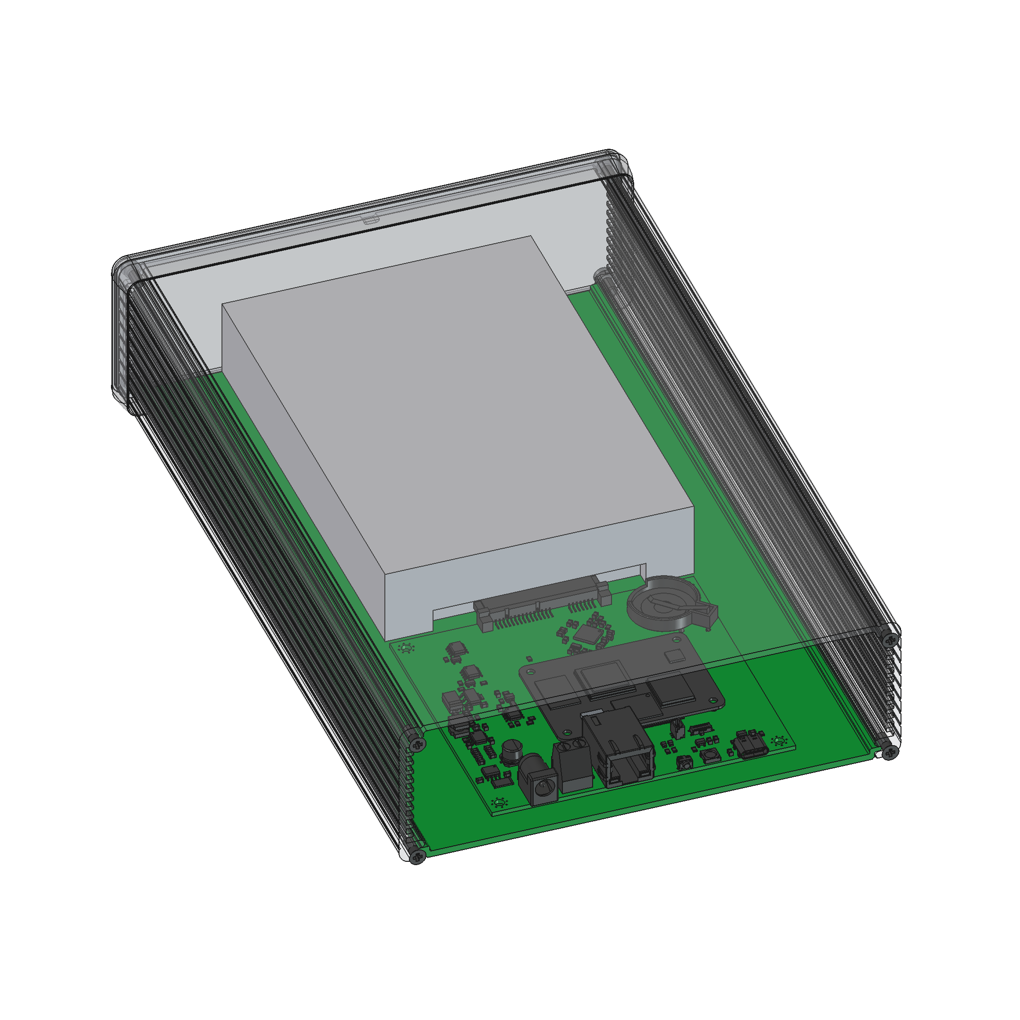
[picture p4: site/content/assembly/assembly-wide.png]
Wide assembly


## Cutouts Required

- Barrel jack or screw terminal (12V DC input)
- RJ45 (Ethernet)
- USB-C
- Tactile button (recessed)
- RGB LED (light pipe or translucent window)

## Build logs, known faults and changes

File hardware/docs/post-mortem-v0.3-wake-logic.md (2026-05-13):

# Post-Mortem: v0.3 Wake/Shutdown Latch Failure

## Summary

The v0.3 wake/shutdown circuit did not work. The CM4 could not be woken by RTC alarm or
button press, and could not be cleanly latched off after shutdown. The logic was
fundamentally inverted.

## Intended Behaviour

1. CM4 boots on power-on
2. Software triggers shutdown → hardware holds GLOBAL_EN LOW → CM4 stays off
3. RTC alarm or button press → drives GLOBAL_EN HIGH → CM4 wakes
4. Cycle repeats

## What Was Built (v0.3)

```
RTC ~INT ──── Q1 gate (2N7002) ──── Q1 drain ──── U6 input (74AHCT1G32 OR gate)
                                                        │
                                              U6 output ──── GLOBAL_EN
```

- U6 (74AHCT1G32): OR gate driving GLOBAL_EN HIGH on wake events
- Q1 (2N7002): N-FET gated by RTC ~INT, pulling one OR gate input LOW/HIGH
- R19 (10K): pull-up on Q1 gate to +3V3

## What Went Wrong

**The logic was inverted.** R19 holds Q1 gate HIGH at power-on, turning Q1 ON, which pulls
the U6 input LOW. With both OR gate inputs LOW, GLOBAL_EN stays LOW → CM4 cannot boot.

The design assumed Q1 ON = wake, but Q1 ON actually = "pull input low" = no wake signal.

Additionally, there was no latch mechanism. After shutdown, CM4 GPIOs go Hi-Z. Without a
latch, GLOBAL_EN floats back HIGH (CM4 internal pull-up) and the CM4 immediately reboots.
The OR gate is combinational — it cannot hold state.

## Root Cause

1. **Logic inversion**: confused active-low (~INT asserts LOW on alarm) with the gate
   drive needed to produce a HIGH on GLOBAL_EN
2. **No state retention**: an OR gate is combinational, not sequential. A latch/flip-flop
   is required to hold the off state after shutdown.

## Workaround Applied

Removed R19. Without the pull-up, Q1 gate floats low, Q1 stays OFF, and GLOBAL_EN floats
HIGH via CM4 internal pull-up. The board boots and runs normally, but:

- RTC wake: non-functional
- Button wake: non-functional
- Clean shutdown latch: non-functional (CM4 reboots immediately after halt)

## Lessons Learned

1. **Simulate the logic before fabrication.** A truth table on paper would have caught the
   inversion. The circuit was designed intuitively rather than systematically.
2. **Combinational logic cannot hold state.** Shutdown requires a latch — the output must
   remain LOW after the control signal (GPIO) goes Hi-Z.
3. **Active-low signals need careful tracking.** DS3231 ~INT is active-low, GLOBAL_EN is
   active-high. Every inversion in the chain must be accounted for.

## Fix (v0.4)

Replace the OR gate + N-FET with a **74LVC1G74 D flip-flop** used as an SR latch:

- ~PRE (set) ← RTC ~INT + button (active-low → forces Q HIGH → boot)
- ~CLR (reset) ← GPIO6 (active-low → forces Q LOW → off)
- Q → GLOBAL_EN

The flip-flop holds state after the control signals release. No logic inversion issues
because ~PRE and ~CLR directly map to the active-low wake sources.

See DESIGN.md "Redesigned Circuit (proposed for v0.4)" for full schematic and analysis.

## Components Affected

| Remove (v0.3) | Add (v0.4) |
|---|---|
| U6 (74AHCT1G32) | 74LVC1G74DP,125 (TSSOP-8) |
| Q1 (2N7002) | R1: 100K ~PRE to GND |
| R16 (GLOBAL_EN pull-up) | R2: 100K ~CLR to +3V3 |
| R18 (Q1 drain pull-up) | C1: 100nF ~PRE to GND |

R19 and R6 (existing pull-ups on ~INT and button) are kept.

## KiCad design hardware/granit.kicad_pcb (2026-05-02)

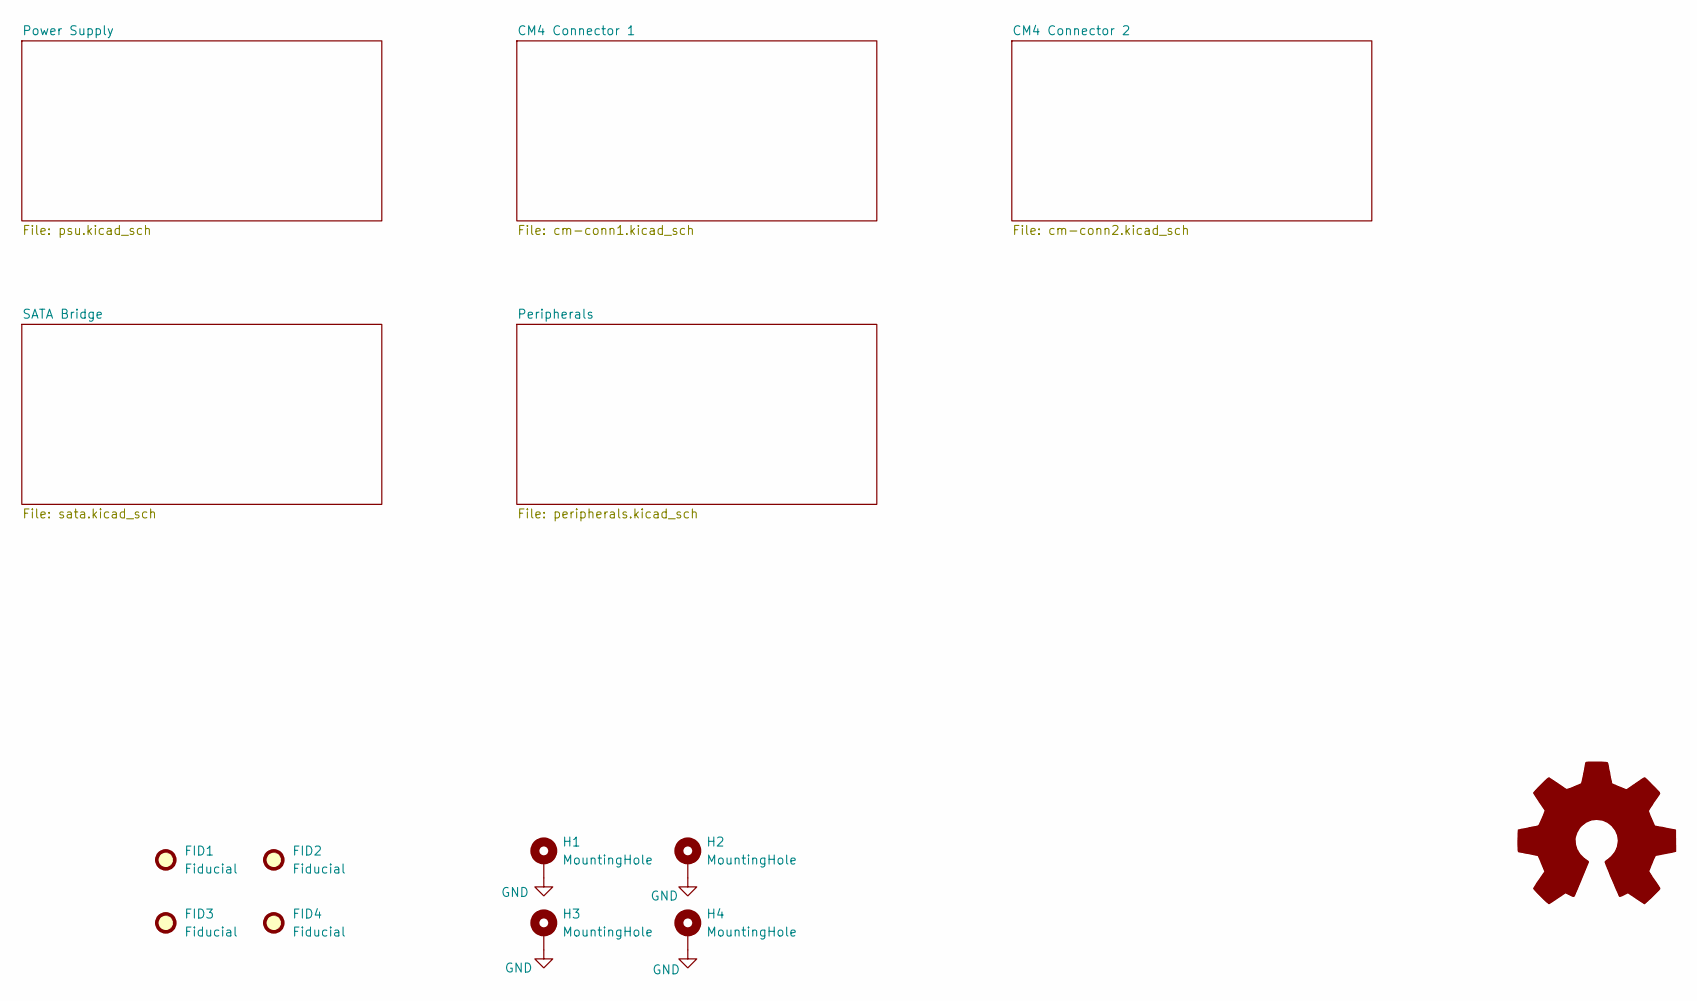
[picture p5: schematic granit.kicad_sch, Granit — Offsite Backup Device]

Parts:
FID1, FID2, FID3, FID4: Fiducial; Fiducial_1mm_Mask2mm
H1, H2, H3, H4: MountingHole; MountingHole_3.2mm_M3_Pad_Via
SYM1: Logo_Open_Hardware_Large; OSHW-Logo2_7.3x6mm_SilkScreen

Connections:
GND: H1.1 (1_1), H2.1 (1_1), H3.1 (1_1), H4.1 (1_1); also elsewhere on the board

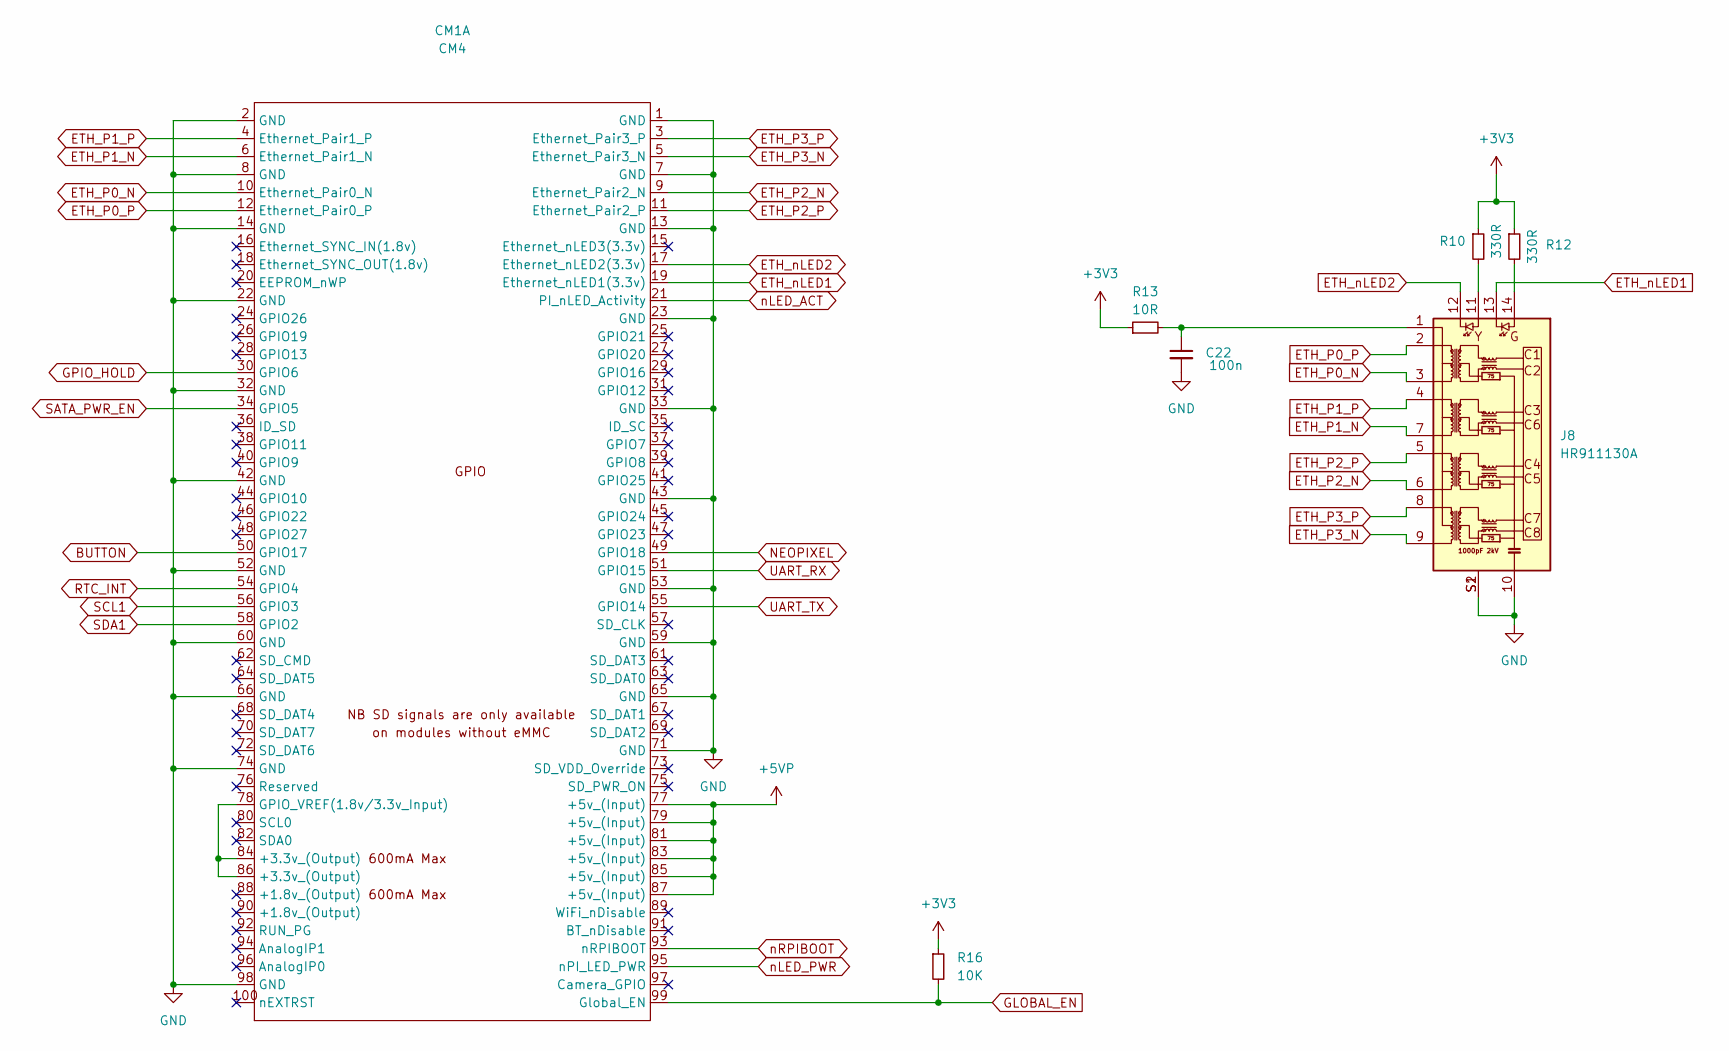
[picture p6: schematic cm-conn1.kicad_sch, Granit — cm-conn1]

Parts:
C22: 100n; C_0805_2012Metric
CM1: CM4; Raspberry-Pi-4-Compute-Module
J8: HR911130A; HANRUN_HR911130A
R10, R12: 330R; R_0805_2012Metric
R13: 10R; R_0805_2012Metric
R16: 10K; R_0805_2012Metric

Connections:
+3V3: R10.1, R12.1, R13.1, R16.1; also elsewhere on the board
+5VP: CM1.77 (+5v_(Input)), CM1.79 (+5v_(Input)), CM1.81 (+5v_(Input)), CM1.83 (+5v_(Input)), CM1.85 (+5v_(Input)), CM1.87 (+5v_(Input)); also elsewhere on the board
BUTTON: CM1.50 (GPIO17); also elsewhere on the board
ETH_P0_N: CM1.10 (Ethernet_Pair0_N), J8.3 (TD1-)
ETH_P0_P: CM1.12 (Ethernet_Pair0_P), J8.2 (TD1+)
ETH_P1_N: CM1.6 (Ethernet_Pair1_N), J8.7 (TD2-)
ETH_P1_P: CM1.4 (Ethernet_Pair1_P), J8.4 (TD2+)
ETH_P2_N: CM1.9 (Ethernet_Pair2_N), J8.6 (TD3-)
ETH_P2_P: CM1.11 (Ethernet_Pair2_P), J8.5 (TD3+)
ETH_P3_N: CM1.5 (Ethernet_Pair3_N), J8.9 (TD4-)
ETH_P3_P: CM1.3 (Ethernet_Pair3_P), J8.8 (TD4+)
ETH_nLED1: CM1.19 (Ethernet_nLED1(3.3v)), J8.13
ETH_nLED2: CM1.17 (Ethernet_nLED2(3.3v)), J8.12
GLOBAL_EN: CM1.99 (Global_EN), R16.2; also elsewhere on the board
GND: C22.2, CM1.1 (GND), CM1.2 (GND), CM1.7 (GND), CM1.8 (GND), CM1.13 (GND), CM1.14 (GND), CM1.22 (GND), CM1.23 (GND), CM1.32 (GND), CM1.33 (GND), CM1.42 (GND), CM1.43 (GND), CM1.52 (GND), CM1.53 (GND), CM1.59 (GND), CM1.60 (GND), CM1.65 (GND), CM1.66 (GND), CM1.71 (GND), CM1.74 (GND), CM1.98 (GND), J8.10 (GND), J8.S1 (SH), J8.S2 (SH); also elsewhere on the board
GPIO_HOLD: CM1.30 (GPIO6); also elsewhere on the board
NEOPIXEL: CM1.49 (GPIO18); also elsewhere on the board
unnamed: CM1.78 (GPIO_VREF(1.8v/3.3v_Input)), CM1.84 (+3.3v_(Output)), CM1.86 (+3.3v_(Output))
unnamed: C22.1, J8.1 (CT_PRI), R13.2
unnamed: J8.11, R10.2
unnamed: J8.14, R12.2
RTC_INT: CM1.54 (GPIO4); also elsewhere on the board
SATA_PWR_EN: CM1.34 (GPIO5); also elsewhere on the board
SCL1: CM1.56 (GPIO3); also elsewhere on the board
SDA1: CM1.58 (GPIO2); also elsewhere on the board
UART_RX: CM1.51 (GPIO15); also elsewhere on the board
UART_TX: CM1.55 (GPIO14); also elsewhere on the board
nLED_ACT: CM1.21 (PI_nLED_Activity); also elsewhere on the board
nLED_PWR: CM1.95 (nPI_LED_PWR); also elsewhere on the board
nRPIBOOT: CM1.93 (nRPIBOOT); also elsewhere on the board

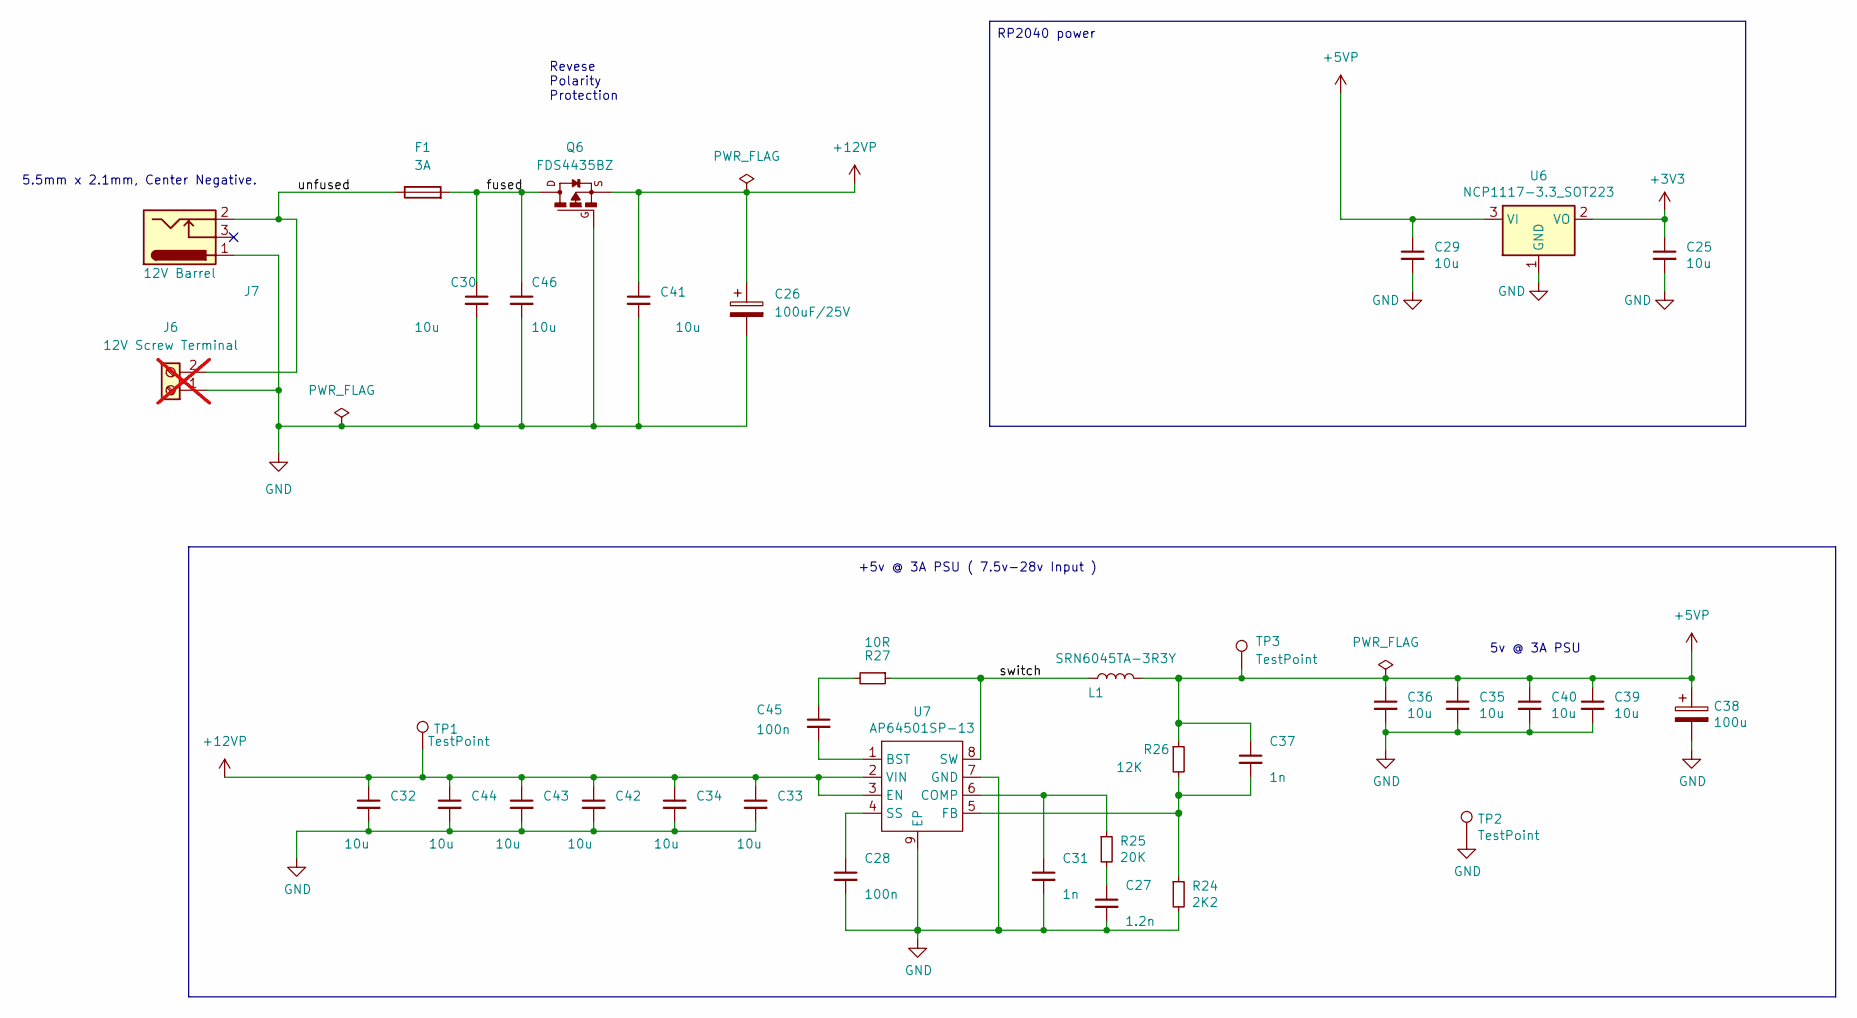
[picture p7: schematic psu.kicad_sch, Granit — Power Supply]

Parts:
C25, C29, C30, C32, C33, C34, C35, C36, C39, C40, C41, C42, C43, C44, C46: 10u; C_0805_2012Metric
C26: 100uF/25V; CP_Elec_6.3x7.7
C27: 1.2n; C_0805_2012Metric
C28, C45: 100n; C_0805_2012Metric
C31, C37: 1n; C_0805_2012Metric
C38: 100u; CP_EIA-7343-31_Kemet-D
F1: 3A; Fuse_2512_6332Metric
J6: 12V Screw Terminal; TerminalBlock_Phoenix_MKDS-1,5-2_1x02_P5.00mm_Horizontal; not fitted
J7: 12V Barrel; BarrelJack_Wuerth_6941xx301002
L1: SRN6045TA-3R3Y; L_Bourns_SRN6045TA
Q6: FDS4435BZ; SO08-E3
R24: 2K2; R_0805_2012Metric
R25: 20K; R_0805_2012Metric
R26: 12K; R_0805_2012Metric
R27: 10R; R_0805_2012Metric
TP1, TP2, TP3: TestPoint; TestPoint_Pad_2.0x2.0mm
U6: NCP1117-3.3_SOT223; SOT-223-3_TabPin2
U7: AP64501SP-13; SOIC-8-1EP_3.9x4.9mm_P1.27mm_EP2.95x4.9mm_Mask2.71x3.4mm_Th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

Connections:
+3V3: C25.1, U6.2 (VO); also elsewhere on the board
+5VP: C29.1, C35.1, C36.1, C37.1, C38.1, C39.1, C40.1, L1.2, R26.1, TP3.1 (1_1), U6.3 (VI); also elsewhere on the board
+12VP: C26.1, C32.1, C33.1, C34.1, C41.1, C42.1, C43.1, C44.1, Q6.1-3, TP1.1 (1_1), U7.2 (VIN), U7.3 (EN); also elsewhere on the board
/Power Supply/fused: C30.1, C46.1, F1.2, Q6.5-8
/Power Supply/switch: L1.1, R27.1, U7.8 (SW)
/Power Supply/unfused: F1.1, J6.2, J7.2
GND: C25.2, C26.2, C27.2, C28.2, C29.2, C30.2, C31.2, C32.2, C33.2, C34.2, C35.2, C36.2, C38.2, C39.2, C40.2, C41.2, C42.2, C43.2, C44.2, C46.2, J6.1, J7.1, Q6.4, R24.2, TP2.1 (1_1), U6.1 (GND), U7.7 (GND), U7.9 (EP); also elsewhere on the board
unnamed: C27.1, R25.2
unnamed: C45.1, R27.2
unnamed: C45.2, U7.1 (BST)
unnamed: C31.1, R25.1, U7.6 (COMP)
unnamed: C37.2, R24.1, R26.2, U7.5 (FB)
unnamed: C28.1, U7.4 (SS)

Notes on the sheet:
5v @ 3A PSU
+5v @ 3A PSU ( 7.5v-28v Input )
Revese Polarity Protection
5.5mm x 2.1mm, Center Negative.
RP2040 power

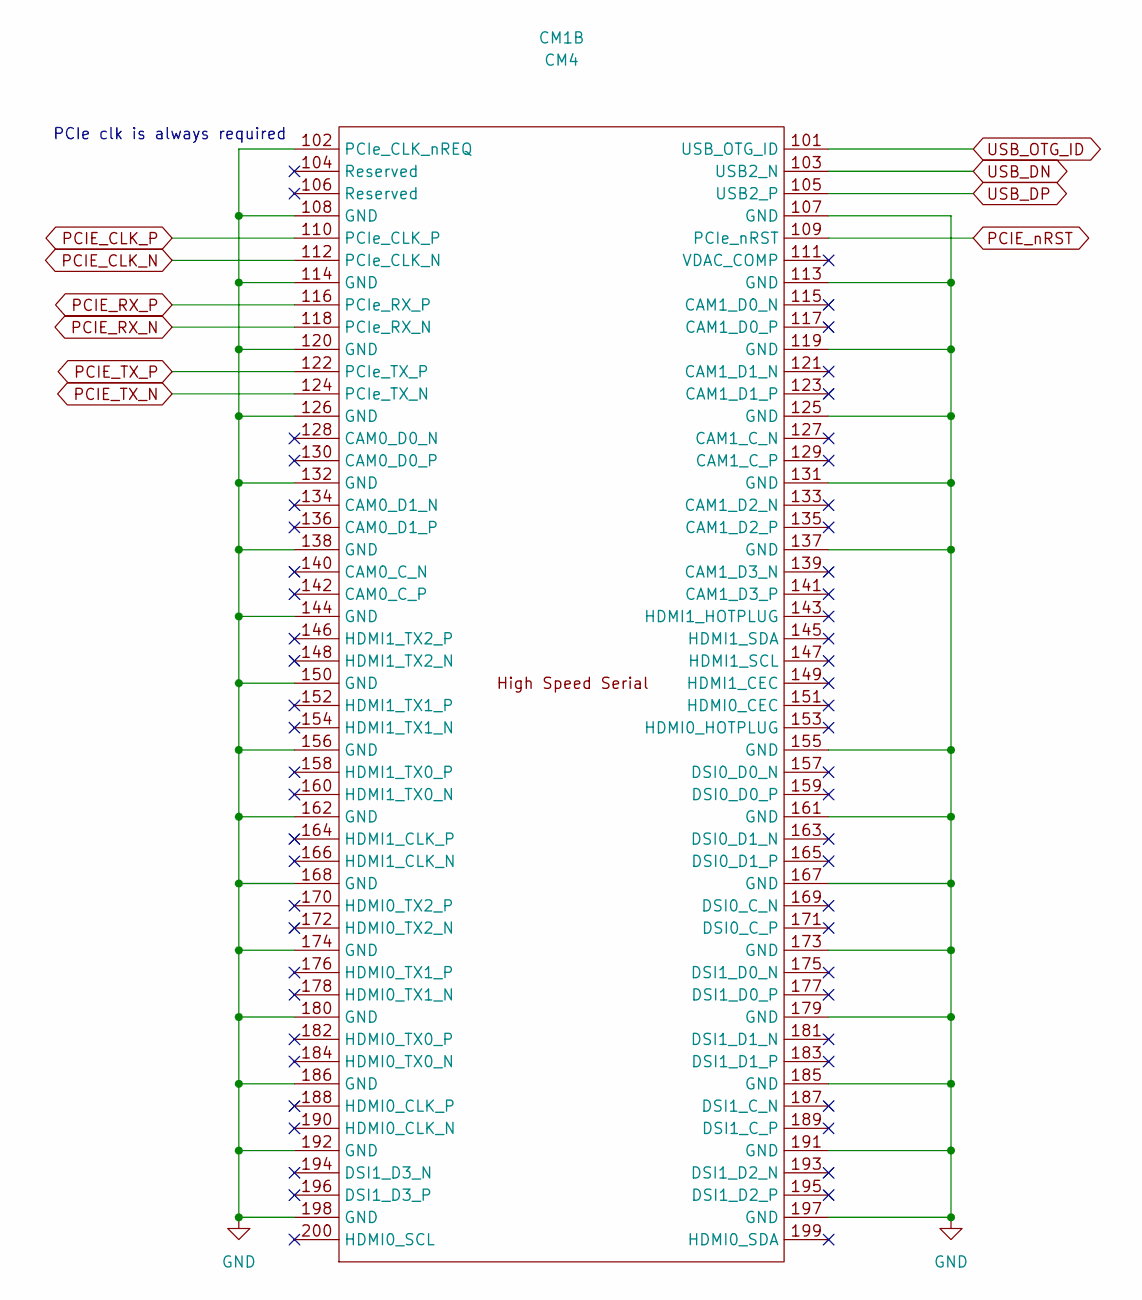
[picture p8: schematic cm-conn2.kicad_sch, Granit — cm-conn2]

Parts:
CM1: CM4; Raspberry-Pi-4-Compute-Module

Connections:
GND: CM1.102 (PCIe_CLK_nREQ), CM1.107 (GND), CM1.108 (GND), CM1.113 (GND), CM1.114 (GND), CM1.119 (GND), CM1.120 (GND), CM1.125 (GND), CM1.126 (GND), CM1.131 (GND), CM1.132 (GND), CM1.137 (GND), CM1.138 (GND), CM1.144 (GND), CM1.150 (GND), CM1.155 (GND), CM1.156 (GND), CM1.161 (GND), CM1.162 (GND), CM1.167 (GND), CM1.168 (GND), CM1.173 (GND), CM1.174 (GND), CM1.179 (GND), CM1.180 (GND), CM1.185 (GND), CM1.186 (GND), CM1.191 (GND), CM1.192 (GND), CM1.197 (GND), CM1.198 (GND); also elsewhere on the board
PCIE_CLK_N: CM1.112 (PCIe_CLK_N); also elsewhere on the board
PCIE_CLK_P: CM1.110 (PCIe_CLK_P); also elsewhere on the board
PCIE_RX_N: CM1.118 (PCIe_RX_N); also elsewhere on the board
PCIE_RX_P: CM1.116 (PCIe_RX_P); also elsewhere on the board
PCIE_TX_N: CM1.124 (PCIe_TX_N); also elsewhere on the board
PCIE_TX_P: CM1.122 (PCIe_TX_P); also elsewhere on the board
PCIE_nRST: CM1.109 (PCIe_nRST); also elsewhere on the board
USB_DN: CM1.103 (USB2_N); also elsewhere on the board
USB_DP: CM1.105 (USB2_P); also elsewhere on the board
USB_OTG_ID: CM1.101 (USB_OTG_ID); also elsewhere on the board

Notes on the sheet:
PCIe clk is always required

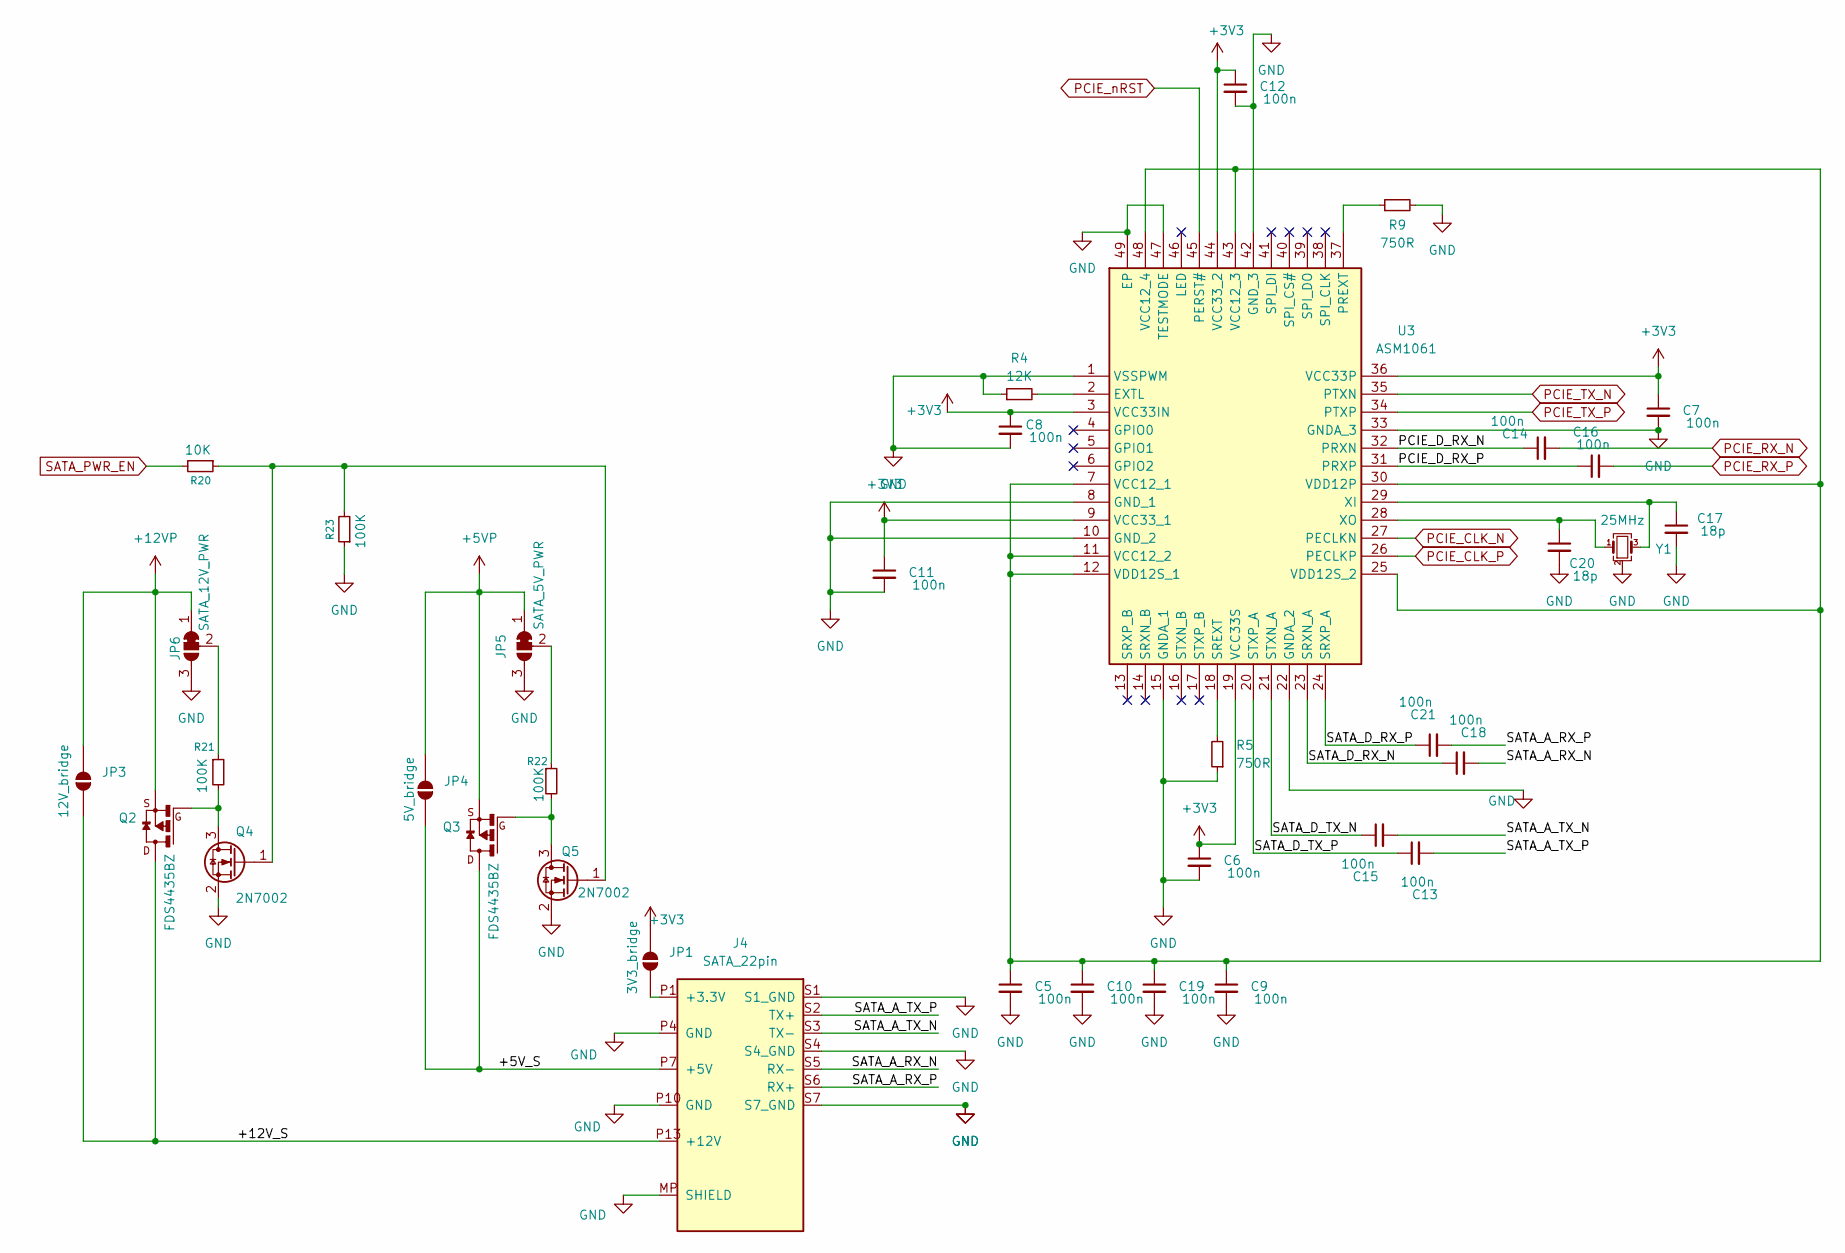
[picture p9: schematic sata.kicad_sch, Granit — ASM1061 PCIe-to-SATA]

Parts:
C5, C6, C7, C8, C9, C10, C11, C12, C13, C14, C15, C16, C18, C19, C21: 100n; C_0805_2012Metric
C17, C20: 18p; C_0805_2012Metric
J4: SATA_22pin; SATA_Amphenol_10029364-001LF_Horizontal
JP1: 3V3_bridge; SolderJumper-2_P1.3mm_Open_Pad1.0x1.5mm
JP3: 12V_bridge; SolderJumper-2_P1.3mm_Open_Pad1.0x1.5mm
JP4: 5V_bridge; SolderJumper-2_P1.3mm_Open_Pad1.0x1.5mm
JP5: SATA_5V_PWR; SolderJumper-3_P1.3mm_Bridged12_Pad1.0x1.5mm
JP6: SATA_12V_PWR; SolderJumper-3_P1.3mm_Bridged12_Pad1.0x1.5mm
Q2, Q3: FDS4435BZ; SO08-E3
Q4, Q5: 2N7002; SOT-23
R4: 12K; R_0805_2012Metric
R5, R9: 750R; R_0805_2012Metric
R20: 10K; R_0805_2012Metric
R21, R22, R23: 100K; R_0805_2012Metric
U3: ASM1061; QFN50P700X700X90-49N-D; Manufacturer_Part_Number ASM1061
Y1: 25MHz; Crystal_SMD_2016-4Pin_2.0x1.6mm

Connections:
+3V3: C6.1, C7.1, C8.1, C11.1, C12.1, JP1.2 (B), U3.3 (VCC33IN), U3.9 (VCC33_1), U3.19 (VCC33S), U3.36 (VCC33P), U3.44 (VCC33_2); also elsewhere on the board
+5VP: JP4.2 (B), JP5.1 (A), Q3.1-3; also elsewhere on the board
+12VP: JP3.2 (B), JP6.1 (A), Q2.1-3; also elsewhere on the board
/SATA Bridge/+5V_S: J4.P7 (+5V), J4.P8 (+5V), J4.P9 (+5V), JP4.1 (A), Q3.5-8
/SATA Bridge/+12V_S: J4.P13 (+12V), J4.P14 (+12V), J4.P15 (+12V), JP3.1 (A), Q2.5-8
/SATA Bridge/PCIE_D_RX_N: C14.1, U3.32 (PRXN)
/SATA Bridge/PCIE_D_RX_P: C16.1, U3.31 (PRXP)
/SATA Bridge/SATA_A_RX_N: C18.2, J4.S5 (RX-)
/SATA Bridge/SATA_A_RX_P: C21.2, J4.S6 (RX+)
/SATA Bridge/SATA_A_TX_N: C15.2, J4.S3 (TX-)
/SATA Bridge/SATA_A_TX_P: C13.2, J4.S2 (TX+)
/SATA Bridge/SATA_D_RX_N: C18.1, U3.23 (SRXN_A)
/SATA Bridge/SATA_D_RX_P: C21.1, U3.24 (SRXP_A)
/SATA Bridge/SATA_D_TX_N: C15.1, U3.21 (STXN_A)
/SATA Bridge/SATA_D_TX_P: C13.1, U3.20 (STXP_A)
GND: C5.2, C6.2, C7.2, C8.2, C9.2, C10.2, C11.2, C12.2, C17.2, C19.2, C20.2, J4.MP (SHIELD), J4.P4 (GND), J4.P5 (GND), J4.P6 (GND), J4.P10 (GND), J4.P11 (GND), J4.P12 (GND), J4.S1 (S1_GND), J4.S4 (S4_GND), J4.S7 (S7_GND), JP5.3 (B), JP6.3 (B), Q4.2 (S), Q5.2 (S), R4.1, R5.1, R9.2, R23.1, U3.1 (VSSPWM), U3.8 (GND_1), U3.10 (GND_2), U3.15 (GNDA_1), U3.22 (GNDA_2), U3.33 (GNDA_3), U3.42 (GND_3), U3.47 (TESTMODE), U3.49 (EP), Y1.2 (G), Y1.4 (G); also elsewhere on the board
unnamed: J4.P1 (+3.3V), J4.P2 (+3.3V), J4.P3 (+3.3V), JP1.1 (A)
unnamed: JP5.2 (C), R22.1
unnamed: JP6.2 (C), R21.1
unnamed: Q2.4, Q4.3 (D), R21.2
unnamed: Q4.1 (G), Q5.1 (G), R20.1, R23.2
unnamed: Q3.4, Q5.3 (D), R22.2
unnamed: R4.2, U3.2 (EXTL)
unnamed: R9.1, U3.37 (PREXT)
unnamed: R5.2, U3.18 (SREXT)
unnamed: C5.1, C9.1, C10.1, C19.1, U3.7 (VCC12_1), U3.11 (VCC12_2), U3.12 (VDD12S_1), U3.25 (VDD12S_2), U3.30 (VDD12P), U3.43 (VCC12_3), U3.48 (VCC12_4)
unnamed: C17.1, U3.29 (XI), Y1.3
unnamed: C20.1, U3.28 (XO), Y1.1
PCIE_CLK_N: U3.27 (PECLKN); also elsewhere on the board
PCIE_CLK_P: U3.26 (PECLKP); also elsewhere on the board
PCIE_RX_N: C14.2; also elsewhere on the board
PCIE_RX_P: C16.2; also elsewhere on the board
PCIE_TX_N: U3.35 (PTXN); also elsewhere on the board
PCIE_TX_P: U3.34 (PTXP); also elsewhere on the board
PCIE_nRST: U3.45 (PERST#); also elsewhere on the board
SATA_PWR_EN: R20.2; also elsewhere on the board

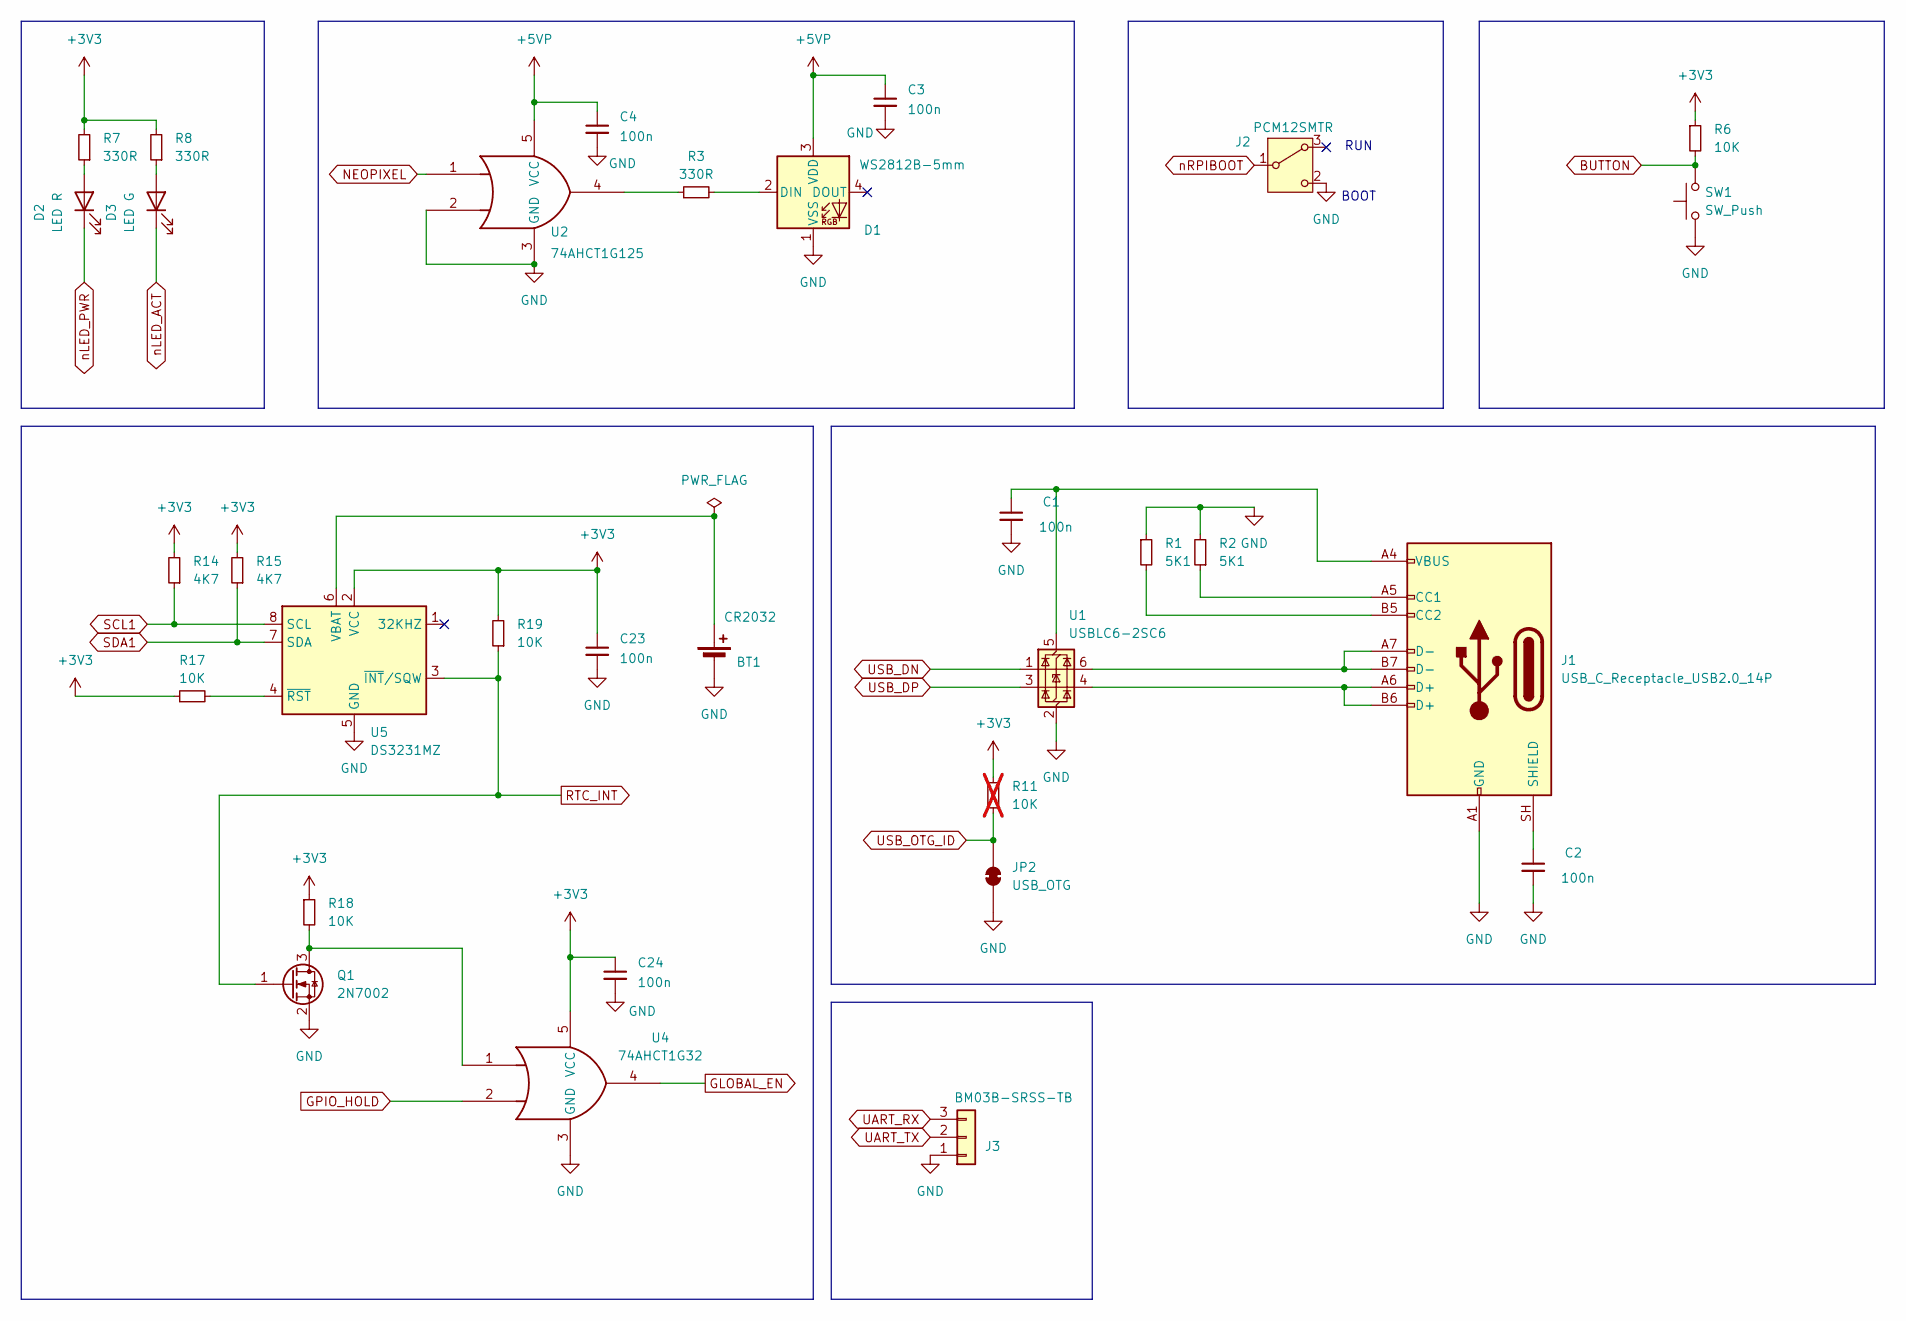
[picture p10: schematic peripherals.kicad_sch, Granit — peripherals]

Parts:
BT1: CR2032; BatteryHolder_Keystone_103_1x20mm
C1, C2, C3, C4, C23, C24: 100n; C_0805_2012Metric
D1: WS2812B-5mm; LED_WS2812B_PLCC4_5.0x5.0mm_P3.2mm
D2: LED R; LED_0805_2012Metric
D3: LED G; LED_0805_2012Metric
J1: USB_C_Receptacle_USB2.0_14P; USB_C_Receptacle_GCT_USB4105-xx-A_16P_TopMnt_Horizontal
J2: PCM12SMTR; SW_SPDT_PCM12
J3: BM03B-SRSS-TB; JST_SH_BM03B-SRSS-TB_1x03-1MP_P1.00mm_Vertical
JP2: USB_OTG; SolderJumper-2_P1.3mm_Bridged_Pad1.0x1.5mm
Q1: 2N7002; SOT-23
R1, R2: 5K1; R_0805_2012Metric
R3, R7, R8: 330R; R_0805_2012Metric
R6, R17, R18, R19: 10K; R_0805_2012Metric
R11: 10K; R_0805_2012Metric; not fitted
R14, R15: 4K7; R_0805_2012Metric
SW1: SW_Push; SW_Push_1P1T-MP_NO_Horizontal_Alps_SKRTLAE010
U1: USBLC6-2SC6; SOT-23-6
U2: 74AHCT1G125; SOT-23-5
U4: 74AHCT1G32; SOT-23-5
U5: DS3231MZ; SOIC-8_3.9x4.9mm_P1.27mm

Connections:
+3V3: C23.1, C24.1, R6.1, R7.2, R8.2, R11.1, R14.2, R15.2, R17.1, R18.1, R19.2, U4.5 (VCC), U5.2 (VCC); also elsewhere on the board
+5VP: C3.1, C4.1, D1.3 (VDD), U2.5 (VCC); also elsewhere on the board
BUTTON: R6.2, SW1.2; also elsewhere on the board
GLOBAL_EN: U4.4; also elsewhere on the board
GND: BT1.2 (-), C1.2, C2.2, C3.2, C4.2, C23.2, C24.2, D1.1 (VSS), J1.A1 (GND), J1.A12 (GND), J1.B1 (GND), J1.B12 (GND), J2.2 (C), J3.1, JP2.1 (A), Q1.2 (S), R1.1, R2.2, SW1.1, U1.2 (GND), U2.2, U2.3 (GND), U4.3 (GND), U5.5 (GND); also elsewhere on the board
GPIO_HOLD: U4.2; also elsewhere on the board
NEOPIXEL: U2.1; also elsewhere on the board
unnamed: BT1.1 (+), U5.6 (VBAT)
unnamed: D1.2 (DIN), R3.2
unnamed: D2.2 (A), R7.1
unnamed: D3.2 (A), R8.1
unnamed: J1.A5 (CC1), R2.1
unnamed: J1.B5 (CC2), R1.2
unnamed: J1.A6 (D+), J1.B6 (D+), U1.4 (I/O2)
unnamed: J1.A7 (D-), J1.B7 (D-), U1.6 (I/O1)
unnamed: C2.1, J1.SH (SHIELD)
unnamed: Q1.3 (D), R18.2, U4.1
unnamed: R3.1, U2.4
unnamed: C1.1, J1.A4 (VBUS), J1.A9 (VBUS), J1.B4 (VBUS), J1.B9 (VBUS), U1.5 (VBUS)
unnamed: R17.2, U5.4 (~RST)
RTC_INT: Q1.1 (G), R19.1, U5.3 (~INT/SQW); also elsewhere on the board
SCL1: R14.1, U5.8 (SCL); also elsewhere on the board
SDA1: R15.1, U5.7 (SDA); also elsewhere on the board
UART_RX: J3.3; also elsewhere on the board
UART_TX: J3.2; also elsewhere on the board
USB_DN: U1.1 (I/O1); also elsewhere on the board
USB_DP: U1.3 (I/O2); also elsewhere on the board
USB_OTG_ID: JP2.2 (B), R11.2; also elsewhere on the board
nLED_ACT: D3.1 (K); also elsewhere on the board
nLED_PWR: D2.1 (K); also elsewhere on the board
nRPIBOOT: J2.1 (B); also elsewhere on the board

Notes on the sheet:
BOOT
RUN

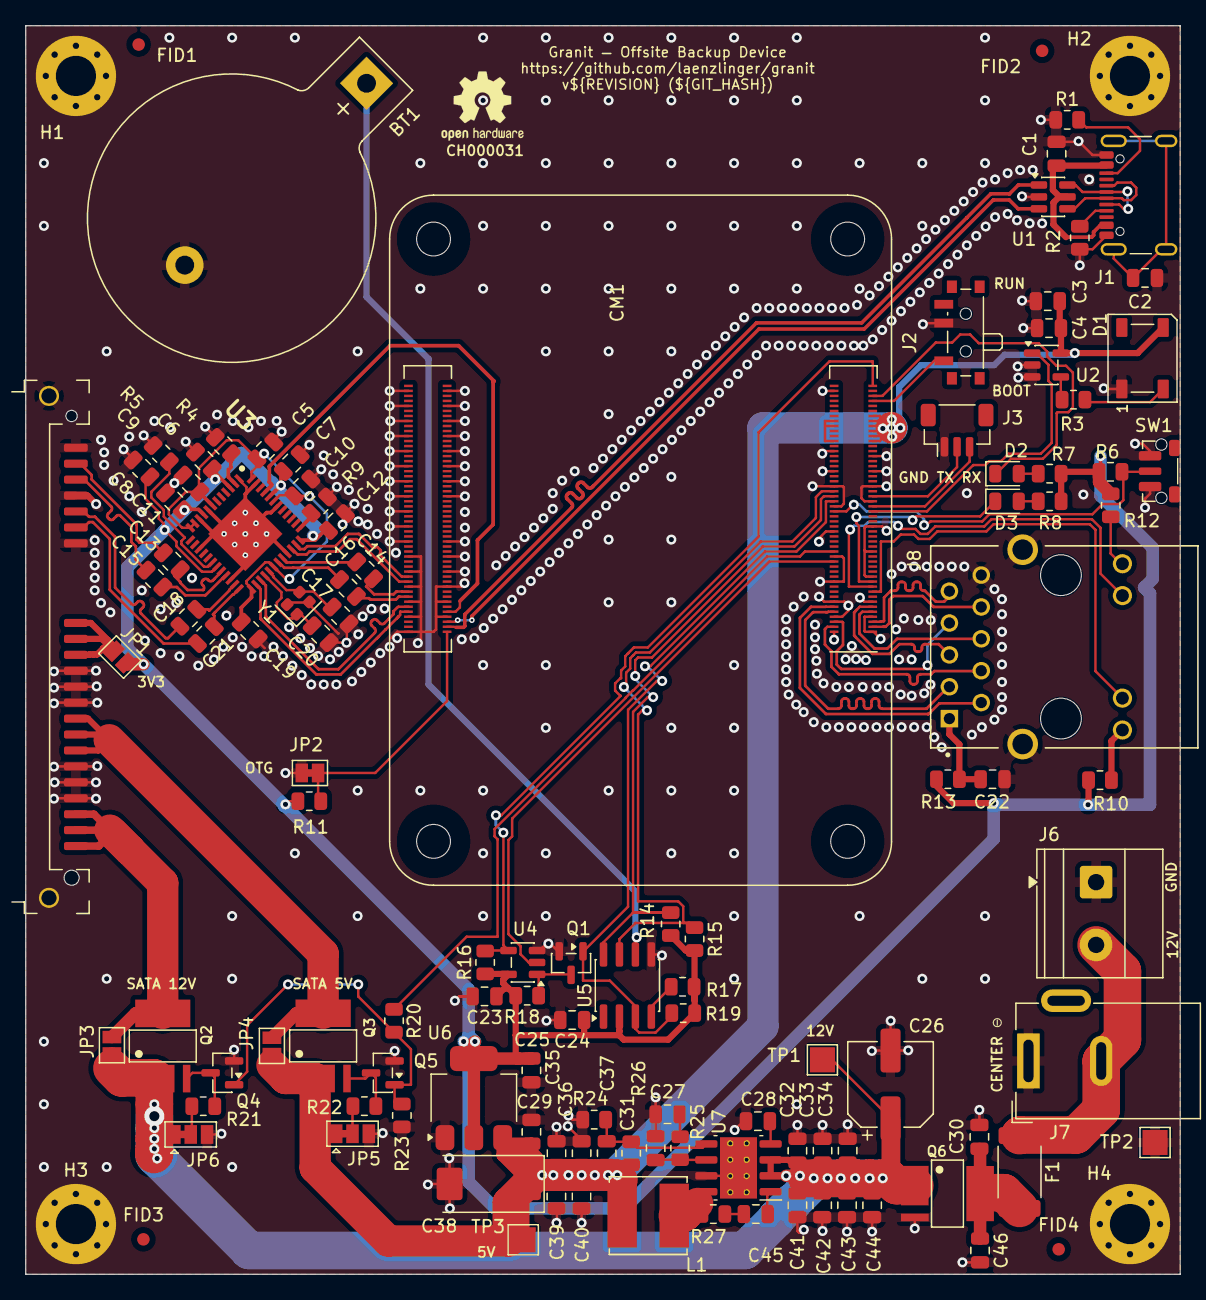
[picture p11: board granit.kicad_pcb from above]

Board: 4 copper layers, 92.0 x 99.5 mm, 120 parts (0 on the bottom side), 87 nets.

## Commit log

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2026-04-12 feat: add 3x3 thermal via grid under IC1 (ASM1061) exposed pad
    [granit.kicad_pcb]
2026-04-12 fix: J8 UART pinout now GND-TX-RX (standard convention)
    Pin 1: GND, Pin 2: TX, Pin 3: RX
    DRC clean, 0 violations.
    [granit.kicad_pcb, peripherals.kicad_sch]
2026-04-12 docs: CRITICAL — PCIe_CLK_nREQ (pin 102) must be tied to GND
    Currently marked no-connect. CM4 won't output PCIe reference clock
    without this, making the ASM1061 SATA bridge non-functional.
2026-04-12 fix: remove false PCIe_CLK_nREQ TODO — pin 102 is already tied to GND
2026-04-12 fix: correct SATA_PWR_EN GPIO number in docs (GPIO5, not GPIO17)
    GPIO5 (pin 34) = SATA_PWR_EN
    GPIO17 (pin 50) = BUTTON
    Documentation had these swapped.
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2026-04-12 fix: remove duplicate GND via, zone refill after verification
    [granit.kicad_pcb]
2026-04-12 feat: add R15 (100K) pull-down on SATA N-FET gate for boot safety
    Ensures SATA power stays OFF during boot before GPIO5 is configured.
    R15 pulls Net-(Q5-G) to GND. Normal operation unaffected (3.0V at gate
    with GPIO5 high, well above 2N7002 threshold).
    DRC: 0 errors, 1 cosmetic warning (Y1 silkscreen).
    [granit.kicad_pcb, sata.kicad_sch]
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2026-04-12 feat: add silkscreen labels (knockout style)
    Front: RUN/BOOT, GND TX RX, 12V, jumper functions, SATA 12V/5V, OTG
    Back: stackup info (JLC04161H-7628, 4L, 100Ω diff)
    [granit.kicad_pcb]
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2026-04-12 feat: add center-negative polarity label near J1 barrel jack
    [granit.kicad_pcb]
2026-04-12 feat: add OSHW logo (SYM1) to schematic and PCB
    [granit.kicad_pcb, granit.kicad_sch]
2026-04-12 feat: add GND/12V knockout labels near J2 screw terminal
    [granit.kicad_pcb]
2026-04-12 feat: replace large polarity footprint with small CENTER ⊖ knockout text
    [granit.kicad_pcb]
2026-04-12 feat: add QR code linking to GitHub repo on front silkscreen
    [granit.kicad_pcb]
2026-04-12 docs: update 3D model, assembly STEP files, and render images
    [granit-pcb.step]
2026-04-12 fix: DRC clean — mirror back silkscreen, clear QR code area, re-enable DRC in kibot
    ERC: 0 errors, 0 warnings
    DRC: 0 violations, 0 unconnected, 0 parity issues
    [granit.kicad_pcb]
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2026-04-12 docs: fix last GPIO17→GPIO5 reference in README
2026-04-12 refactor: reannotate PCB by position + rename IC1 to U prefix
    All reference designators renumbered top-to-bottom, left-to-right.
    ASM1061 changed from IC to U prefix.
    ERC: 0 errors. DRC: 0 violations. Parity: 0 issues.
    [cm-conn1.kicad_sch, granit.kicad_pcb, granit.kicad_sch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]
2026-04-12 fix: sync PCB net names after reannotation
    DRC: 0 violations, 0 parity issues.
    [granit.kicad_pcb]
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2026-04-12 feat: add InvenTree IPN field to all schematic symbols
    102 components mapped to 41 unique InvenTree part numbers.
    IPN format: category prefix + sequential number (e.g. C-001, R-002, U-009).
    [cm-conn1.kicad_sch, cm-conn2.kicad_sch, peripherals.kicad_sch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]
2026-04-12 chore: remove redundant supplier fields, keep IPN as single link to InvenTree
    Removed: Supplier, Digikey, Notes, KiLib_Generator, Mouser, Arrow fields.
    InvenTree IPN is now the only external reference in the schematic.
    [cm-conn1.kicad_sch, cm-conn2.kicad_sch, granit.kicad_pcb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]
2026-04-12 feat: complete IPN assignment for all BOM parts
    All components now have InvenTree IPN field.
    Added IPN to granit library symbols (ASM1061, FDS4435BZ, AP64501).
    Added Q-003 to 2N7002 instances.
    Only TestPoints have no IPN (not purchaseable).
    [granit.kicad_pcb, peripherals.kicad_sch, psu.kicad_sch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]
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2026-04-12 chore: use existing SK6812/WS2812B stock (D-007) instead of D-008
    [peripherals.kicad_sch]
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2026-04-12 docs: save LCSC order cart (17 parts for v0.3.0)
    [lcsc-order.csv]
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2026-04-12 docs: add board width fix to v0.3.0 respin (100mm → 99mm for Hammond card guides)
2026-04-12 docs: board width 99.5mm (0.25mm clearance per side in Hammond card guides)
2026-04-13 docs: RJ45 solved — RB1-125BAK1A is drop-in replacement, available on LCSC
2026-04-13 docs: final LCSC cart with RB1-125BAK1A (drop-in GbE MagJack)
    [lcsc-order.csv]
2026-04-13 wip: HR911130A RJ45 MagJack symbol and footprint (not routed)
    Hanrun HR911130A GbE MagJack as replacement for RB1-125B8G1A.
    Signal pins are on opposite side — requires full re-route of Ethernet area.
    Parked for later.
    [cm-conn1.kicad_sch]
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2026-04-13 feat: swap RJ45 MagJack to HR911130A (Hanrun GbE)
    - New symbol and footprint in granit library
    - Pin mapping follows TIA-568B MDI standard
    - All 4 Ethernet diff pairs routed with 100Ω impedance
    - Pair 1 uses via + bottom trace for length matching
    - DRC: 0 violations, 0 unconnected, 0 parity issues
    [cm-conn1.kicad_sch, granit.kicad_pcb]
2026-04-13 feat: swap C26 footprint to CP_Elec_6.3x7.7 (easier to source on LCSC)
    [granit.kicad_pcb, psu.kicad_sch]
2026-04-13 fix: restore SATA TX+ pin number to S2 (was corrupted by HR911130A shield pin remap)
    DRC: 0 violations, 0 parity issues
    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
    [sata.kicad_sch]
2026-04-13 feat: swap crystal Y1 to 2016 4-pin (easier to source)
    Changed from Crystal_SMD_3215-2Pin to Crystal_SMD_2016-4Pin_2.0x1.6mm.
    Re-routed PCIe area around new crystal placement.
    ERC: 0 errors, 0 warnings. DRC: 0 violations.
    [granit.kicad_pcb, sata.kicad_sch]
2026-04-13 feat: shrink board width to 99.5mm for Hammond 1455 card guide clearance
    Board: 92 × 99.5mm (was 92 × 100mm).
    Hammond 1455 card guide slot: 100.00 ±0.51mm.
    ERC: 0. DRC: 0.
    [granit.kicad_pcb]
2026-04-13 chore: shrink zone outlines and refill for 99.5mm board width
    [granit.kicad_pcb]
2026-04-13 docs: update LCSC cart with HR911130A, update InvenTree
    [lcsc-order.csv]
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2026-04-13 fix: change crystal load caps from 15pF to 18pF (matches 12pF load spec)
    C17, C20: 15pF → 18pF (C-015, CML0805C0G180JT50V)
    C_load = (18×18)/(18+18) + 3pF stray = 12pF ✅
    [sata.kicad_sch]
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2026-04-13 fix: add missing IPNs for J4 (SATA), J5 (HR911130A), Y1 (crystal)
    [cm-conn1.kicad_sch, granit.kicad_pcb, sata.kicad_sch]
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2026-04-15 Add Hugo-based project site (replaces KiBot navigate page)
    Uses hugo-kicad-site theme for versioned multi-page documentation.
    Pages: overview, schematic (KiCanvas), gallery, downloads, design notes.
    CI builds full Hugo site per version and deploys to gh-pages/<version>/.
    Refs: pedalboard/pedalboard-hw#16
2026-04-15 Fix KiCanvas: add kicadDir param for hardware/ subdir
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2026-04-15 Fix: config override YAML indentation (heredoc → printf)
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2026-04-15 Fix: run KiBot diff from repo root for proper git access
    [cm-conn1.kicad_sch, cm-conn2.kicad_sch, granit-boardview.brd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]
2026-04-15 Revert "Fix: run KiBot diff from repo root for proper git access"
    This reverts commit 72fc4364839ab3caccd24fd4d14802316f57ccd4.
    [cm-conn1.kicad_sch, cm-conn2.kicad_sch, granit-boardview.brd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]
2026-04-15 GitHub social icon links to tag/branch per version
    [granit.kicad_pcb]
2026-04-15 Move 3D render to site/static/images, README uses gh-pages URL
    [granit.kicad_pcb]
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2026-04-16 Switch to reusable workflow from hugo-kicad-site
    - Replace inlined CI with workflow_call
    - Remove unused params from site config
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2026-04-16 Switch assembly output from GLB to colored 3MF
    FreeCAD doesn't support GLB export — the previous .glb files were
    empty (0 meshes, 0 buffer bytes). Replace with 3MF which FreeCAD
    supports natively, then post-process the XML to inject per-object
    colors (case=silver, PCB=green, HDD=dark gray).
    Also configure the site's Online 3D Viewer to serve the 3MF files
    on the assembly page.
    [assembly-slim.3mf, assembly-wide.3mf]
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2026-04-16 Remove case lid from assembly to show internals
    [assembly-slim.3mf, assembly-wide.3mf]
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2026-04-16 Fix assembly camera: look down from above into open case
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2026-04-16 Fix assembly orientation: bottom plate down
    [assembly-slim.3mf, assembly-wide.3mf]
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2026-04-16 update hugo-kicad-site theme (KiCanvas fix)
2026-04-17 update hugo-kicad-site theme (fix kicanvas attributes)
2026-04-17 update theme (fullscreen button fixes)
2026-04-17 switch to combined release page type
    Replaces separate Changes and Downloads pages with a single Release page.
2026-04-17 switch to combined board page (schematic + gallery + design notes)
    Replaces separate Schematic, Gallery, and Design Notes pages.
2026-04-17 Add pi-gen based OS image build for Granit appliance
    Custom stage on top of Raspberry Pi OS Lite:
    - PCIe SATA (ASM1061) and DS3231 RTC device tree config
    - GPIO5 HDD power control service
    - rclone-based backup sync with daily RTC wake cycle
    - SSH hardening, fail2ban, UFW, automatic security updates
    - First-boot config via /etc/granit/sync.conf
2026-04-17 Fix image CI: symlink qemu-arm-static to qemu-arm
2026-04-17 Remove TODO.md — tracked as GitHub issues (#1-#9)
    All actionable items converted to issues. Design reference
    info already in hardware/DESIGN.md.
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2026-04-17 Add parametric OpenSCAD end plate design (#4)
    Supports both slim (1455L) and wide (1455T) Hammond cases.
    Cutouts for: barrel jack, RJ45, USB-C, button, LED.
    Positions derived from KiCad PCB connector placement.
    Generate STL: openscad -o end-plate.stl -D 'variant="slim"' end-plate.scad
    [end-plate.scad]
2026-04-17 Replace stock end plate with cutout version in 3D assembly
    Connector-side end plate now shows cutouts for barrel jack,
    RJ45, USB-C, button, and LED (from OpenSCAD design).
    [assembly-slim.3mf, assembly-wide.3mf, end-plate-slim.stl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]
2026-04-17 Fix end plate cutout positions: PCB Y maps to plate X
    Connector positions now correctly derived from KiCad PCB
    coordinates. The PCB's right edge (X=112) faces the end plate,
    so KiCad Y-axis maps to the plate's horizontal axis.
    [assembly-slim.3mf, assembly-wide.3mf, end-plate-slim.stl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]
2026-04-17 Fix end plate cutout positions from actual KiCad footprint coordinates
    [assembly-slim.3mf, assembly-wide.3mf, end-plate-slim.stl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]
2026-04-17 End plate cutout dimensions from datasheets
    - J7 barrel jack: center 5.0mm, 11x11mm opening
    - J8 RJ45: center 7.35mm, 16.2x11.7mm opening
    - J1 USB-C: center 3.31mm, 9.0x3.2mm opening
    - SW1 button: center 1.5mm, Ø3mm hole
    - D1 LED: center 0.7mm, Ø3mm light pipe hole
    [assembly-slim.3mf, assembly-wide.3mf, end-plate-slim.stl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]
2026-04-17 End plate: bottom-align all connector cutouts to PCB surface
    All rectangular cutouts (barrel jack, RJ45, USB-C) now share
    the same bottom edge at PCB surface level. Button and LED holes
    are at matching height (1.5mm above PCB) with same Ø3mm diameter
    for a clean look — LED uses a custom 3D-printed light pipe.
    [assembly-slim.3mf, assembly-wide.3mf, end-plate-slim.stl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]
2026-04-17 Fix end plate screw holes from Hammond STEP: M4 Ø4.2mm, 4mm inset
    [assembly-slim.3mf, assembly-wide.3mf, end-plate-slim.stl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]
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2026-04-17 Fix end plate screws: #4-40/M3 per Hammond 1455 datasheet
    [assembly-slim.3mf, assembly-wide.3mf, end-plate-slim.stl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]
2026-04-17 Add rounded corners to end plate (r=3.94mm from Hammond STEP)
    Plate is now 3D-printable with accurate corner radii.
    [assembly-slim.3mf, assembly-wide.3mf, end-plate-slim.stl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]
2026-04-17 Export STEP alongside 3MF, end plate as Part solid
    End plate converted from Mesh to Part::Feature so it appears
    in STEP export. Both .step and .3mf files now include the
    cutout end plate.
    [assembly-slim.3mf, assembly-wide.3mf]
2026-04-17 Build end plate with native Part primitives for clean STEP holes
    Replaced STL mesh import with FreeCAD Part boolean operations:
    rounded rectangle, box/cylinder cuts for connectors, countersunk
    screw holes. STEP export now has proper through-holes.
    [assembly-slim.3mf, assembly-wide.3mf, end-plate-slim.stl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]
2026-04-17 Single source of truth: OpenSCAD for end plate, remove FreeCAD duplicate
    - End plate defined only in end-plate.scad (OpenSCAD)
    - Assembly imports STL mesh for 3MF viewer
    - Removed STEP assembly export (mesh objects not compatible)
    - Removed duplicate FreeCAD Part construction
    [assembly-slim.3mf, assembly-wide.3mf]
2026-04-17 Merge end plate directly from OpenSCAD 3MF (preserves holes)
    FreeCAD's mesh pipeline was losing hole topology. Now the
    end plate mesh is taken directly from OpenSCAD's 3MF export
    and merged into the assembly 3MF during post-processing.
    [assembly-slim.3mf, assembly-wide.3mf, end-plate-slim.3mf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]
2026-04-17 Fix end plate axis mapping in assembly (OpenSCAD XYZ → assembly coords)
    [assembly-slim.3mf, assembly-wide.3mf]
2026-04-17 Fix end plate normals: flip triangle winding after axis remap
    [assembly-slim.3mf, assembly-wide.3mf]
2026-04-17 Fix: add EndPlate to 3MF build section (was invisible)
    [assembly-slim.3mf, assembly-wide.3mf, endplate-extracted.3mf]
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2026-04-17 Fix end plate transform matrix
    [assembly-slim.3mf, assembly-wide.3mf]
2026-04-17 Fix end plate transform: correct side and height
    [assembly-slim.3mf, assembly-wide.3mf]
2026-04-17 Fix wide end plate height to match Hammond STEP (53.6mm)
    [assembly-slim.3mf, assembly-wide.3mf, end-plate-slim.3mf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]
2026-04-17 Fix end plate transform offsets for both case variants
    [assembly-slim.3mf, assembly-wide.3mf]
2026-04-17 Fix end plate: flip right side up, cutouts near PCB at bottom
    [assembly-slim.3mf, assembly-wide.3mf]
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2026-04-18 Test: remove winding flip on end plate
    [assembly-slim.3mf, assembly-wide.3mf, granit-pcb.step]
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2026-04-18 Add STEP export for web viewer (o3dv renders holes correctly in STEP)
    [assembly-slim.3mf, assembly-wide.3mf]
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2026-04-18 Refactor end plate: 2D profile for DXF/CNC, 3D for STL/printing
    Single source: end-plate.scad with mode parameter
    - mode=2d → DXF for CNC machining
    - mode=3d → STL for 3D printing
    - Countersink only in 3D mode (2D shows through-hole only)
    [assembly-slim.3mf, assembly-wide.3mf, end-plate-slim.3mf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]
2026-04-18 Remove 3MF files (STL for printing, DXF for CNC, STEP for viewer)
    [assembly-slim.3mf, assembly-wide.3mf, end-plate-slim.3mf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]
2026-04-18 STEP-only assembly: remove Z-up flip and 3MF export
    [assembly-slim.3mf, granit-pcb.step]
2026-04-18 Fix Makefile for STEP screenshots, update both images
    [assembly-slim.3mf, granit-pcb.step]
2026-04-18 Restore Z-up flip for STEP export and screenshots
    [granit-pcb.step]
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2026-04-18 Remove Z-up flip: use native Y-up for both o3dv and f3d (--up=+Y)
    [granit-pcb.step]
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2026-04-18 Screenshot: use f3d default Z-up so model lies flat like web viewer
    [granit-pcb.step]
2026-04-18 Update Makefiles and add mise/node for screenshot toolchain
    - mise: add node for puppeteer dependency
    - mechanical/Makefile: add end-plates target (STL+DXF), fix comments
    - mechanical/package.json: puppeteer dependency
    - screenshot via o3dv headless Chromium
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2026-04-18 Fix: apply Z-up flip to end plate, remove stale screenshot.html
2026-04-18 Remove all rotation — native Y-up, o3dv handles it correctly
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2026-04-18 Reduce PCB STEP: connectors only, no CM4 or SMD parts (4MB vs 19MB)
    [granit-pcb.step]
2026-04-18 Fix Makefile component filter to match PCB export
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2026-04-18 Fix barrel jack cutout: 9x9mm per datasheet (was 11x11mm)
    [assembly-slim.step, assembly-wide.step, end-plate-slim.dxf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]
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2026-04-18 Enable hardware watchdog (bcm2835_wdt) — fixes #5
    - dtparam=watchdog=on in config.txt
    - systemd RuntimeWatchdogSec=15 (auto-reboot on 15s hang)
    - Critical for unattended remote device
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2026-04-18 hw: use REVISION text variable from mise env
    Replace hardcoded rev '0.1' with ${REVISION} in all schematics and PCB.
    Set via mise.toml (currently 0.3.0), passed through Makefile --define-var
    and KiBot set_text_variables. Defaults to 'dev' if unset.
    [cm-conn1.kicad_sch, cm-conn2.kicad_sch, granit.kicad_pcb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]
2026-04-18 hw: add REVISION to project text variables
    KiCad needs the variable defined in .kicad_pro for ${REVISION}
    to resolve in title blocks. KiBot set_text_variables overwrites
    the value at build time.
2026-04-21 ci: switch to kicad10_auto_full container
    Replace kicad/kicad:10.0 + manual KiBot install with
    ghcr.io/inti-cmnb/kicad10_auto_full:dev which includes KiBot pre-installed.
2026-04-21 kibot: fix blender_export to match pedalboard-hw config
    Use pcb3d (PCB2Blender), outputs list, and point_of_view list
    with top/30deg/bottom views.
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2026-04-22 ci: re-add kicad-packages3d install (GitLab 3D downloads fail for KiCad 10)
2026-04-22 Revert kibot_install (KICAD10_3DMODEL_DIR now set in reusable workflow)
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2026-04-24 fix: correct SATA slot position on HDD models and align drive to connector
    The SATA connector on HDDs is offset ~16-19mm from the drive center
    (per SFF-8201/8301). The previous HDD models had incorrectly sized and
    positioned slots, and the assembly centered the drive body instead of
    aligning the SATA connector with J4 on the PCB.
    Changes:
    - Add mechanical/hdd.scad (OpenSCAD parametric HDD model)
    - Add mechanical/stl2step.py (STL→STEP conversion helper)
    - Fix slot position/size per SFF-8223 connector spec
    - Align HDD placement to SATA connector, not drive center
    - Add hdd-models target to Makefile
    Refs: #27
    [2.5inch_HDD.step, 3.5inch_HDD_NAS.step, hdd.scad]
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2026-04-25 site: add v0.3.0 slim case fit warning (issue #1)
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2026-04-26 pnp: fix feeder assignment (group LEDs, add inductor, fix NCP1117 part-id)
    [feeders.csv]
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2026-05-01 update feeder map: fix fuse tape type to BlackPlastic
2026-05-01 update feeder map: fix LED 0805 tape type to BlackPlastic
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2026-05-01 pnp: correct board Z to 8.6mm
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2026-05-02 fix: correct R17/R19 silkscreen label positions
    Fixes #34
    [granit.kicad_pcb]
2026-05-02 workaround: mark R19 (RTC_INT pull-up) as DNP
    R19 pulls Q1 gate high at power-on, preventing CM4 boot by
    holding GLOBAL_EN low. Mark as DNP until the wake circuit is
    redesigned (see #31).
    [peripherals.kicad_sch]
2026-05-03 fix: center SATA slot on HDD models
    The SATA connector cutout was positioned near one edge of the drive
    (1.5mm from ref edge for 2.5", 14.4mm for 3.5"). In reality, the
    SATA connector is centered on the drive width.
    Fixed slot position in hdd.scad and updated hdd_sata_center_y in
    assembly.py to match (half drive width).
    Verified against physical 2.5" HDD measurement: ~10mm clearance
    to board edge on both sides.
    Fixes #27
    [2.5inch_HDD.step, 3.5inch_HDD_NAS.step, hdd.scad]
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2026-05-03 rebuild assembly models with corrected HDD slot position
    [assembly-slim.step, assembly-wide.step]
2026-05-03 fix: update assembly comment — SATA connector is centered on HDD
2026-05-03 fix SATA connector offset per SFF-8201/8301 (not centered on drive)
    [2.5inch_HDD.step, 3.5inch_HDD_NAS.step, assembly-slim.step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]
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2026-05-10 Assembly page: use call-partial shortcode for flexible layout
    Place 3D viewers after variant descriptions instead of at the top.
    Removes type: assembly in favor of default layout + shortcode.
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2026-05-10 Use Hextra shortcodes: callouts, tabs, steps, details
    - Assembly: callout for errata, tabs for enclosure variants
    - Software: steps for backup cycle and provisioning, tabs for monitoring, details for security
    - Board: callout for power budget, details for design decisions
2026-05-10 Fix double 3D viewers: set type: default to avoid assembly layout
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2026-05-16 mechanical: parametric Hammond 1455 case and compact sandwich assembly
    Accurate parametric Hammond 1455 case model (OpenSCAD):
    - Pure extrusion profile with PCB slots, boss blocks, belly plate groove
    - Decorative grooves, corner radii, all dimensions from STEP analysis
    - Profiles: J, K, L, N, T with correct slot counts
    - Separate body, lid, and end plate render modes
    Three enclosure variants:
    - Slim: 1455L2201 (103×30.5×220mm) — 2.5" HDD side-by-side
    - Compact: 1455T1601 (165×51.5×160mm) — 3.5" HDD sandwich
    - Wide: 1455T2601 (165×51.5×260mm) — 3.5" HDD side-by-side
    Assembly pipeline:
    - All case parts generated from 1455-case.scad (no proprietary STEP files)
    - End plates with co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
    [1455-case.scad, 2.5inch_HDD.step, 3.5inch_HDD_NAS.step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]
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
